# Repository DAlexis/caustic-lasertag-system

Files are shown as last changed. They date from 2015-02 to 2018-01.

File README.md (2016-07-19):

# Caustic Lasertag System
For Russian description scroll down the page.

Описание на русском --- внизу страницы.

## Overview
Caustic project is a full-featured outdoor and indoor wireless lasertag system. It consists of principial schemes, PCBs and firmware for devices used in lasertag game. For now, system consists of:
  - Player's gun
  - Player's sensor to detect shoots
  - Smart control point for 'capture the point' game and some other things
  - Bluetooth bridge that provide interconnection between your smartphone and all the devices in game near bridge
  - Android application (currently alpha state) to control the game and change settings

Caustic Lasertag System licensed under GPLv3. Third party code used in project may be licensed under other licences, see corresponding files and comments in the sources. Copyright 2016, see AUTHORS file.

## Project structure
Here is a directories description:
  - `Android/` --- Android application to control the game and change settings 
  - `cpp-sources/` --- MCU firmware. Here:
     - `bootloader-usb/` is a reference to https://github.com/DAlexis/stm32-usb-bootloader --- bootloader that supports cardreader functionality and flash controller from file `flash.bin`
     - `universal-device/` --- universal firmware for any Caustic LTS device.  
  - `Docs/` --- some datasheets and useful documents for project
  - `media/` --- sounds and its raws. Most of them were get from https://www.freesound.org/
  - `schematic/` --- electic schemes, PCBs and gerbers made with KiCad
  - `tools/` --- some scripts to simplify primitive jobs
  - `sdcards/` --- samples of devices' SD cards containment

## How to build firmware
Now only Linux OS supported to build Caustic LTS firmware, but I use `CMake` so add Windows support should not be a very complicated task.

You need to install `cmake`, `arm-none-eabi-gcc` compiler **with** `arm-none-eabi-newlib` and `arm-none-eabi-binutils` installed, and installation dirs should be in `$PATH`. Simply installation from your distro's repository usually enough. To flash the MCU with ST-link programmer you should install `stlink` utility. Then:

  - Clone this repository:
    
    `git clone https://github.com/DAlexis/caustic-lasertag-system.git`
  - Go to `cpp-sources` directory:
    
    `cd caustic-lasertag-system/cpp-sources`
  - Download git submodule containing bootloader:
    
    `git submodule init && git submodule update`
  - Run `build.sh` for debug build and `build.sh release` for release one

Then, to program the board:
  - Connect ST-link programmer to the board and to yout PC's USB
  - To flash main firmware run
  
    `flash-universal-device.sh`
  - To flash bootloader run
  
    `flash-bootloader.sh`
    To flash release version add `release` parameter to both scripts

    **NOTE:** flashing bootloader means removing previous firmware. To flash main program after flashing bootloader you should rename `universal-device.bin` to `flash.bin` and copy it to sd-card's root, then reboot device.

  - Then, copy proper sh-card containment to your device's sd-card. For example, for gun you should copy all files and dirs from `sdcards/rifle` to gun's sd-card.

# Лазертаг-система Caustic
Caustic --- это полноценная беспроводная система для внеаренного и аренного лазертага. Проект содержит принципиальные схемы, печатные платы, прошивки микроконтроллера и другой необходимый код. На данный момент, система включает:
  - Оружие игрока
  - Датчики попадания ("головная повязка") для игрока
  - Умная контрольная точка для игры в "захват точки", поддерживающая другие вспомогательные функции
  - Bluetooth-мост, позволяющий подключать смартфон одновременно к любому количеству устройств системы
  - Приложение для Android (на данный момент в альфа-версии) для управления игрой и настройки игровых устройств

Система Caustic лицензирована под GPLv3. Система включает код тертьих лиц, который может быть лицензирован под другими лицензиями. Copyright 2016, Алексей Булатов. 

## Структура проекта
Проект устроен следующим образом:
  - `Android/` --- Приложение для Android 
  - `cpp-sources/` --- Прошивка для контроллера
     - `bootloader-usb/` --- ссылка на https://github.com/DAlexis/stm32-usb-bootloader --- загрузчик, превращающий устройство в кардридер, если при запуске оно подключено к компьютеру по USB. Прошивает контроллер из файла `flash.bin`
     - `universal-device/` --- универсальная прошивка для любого устройства системы Caustic
  - `Docs/` --- даташиты, документация и некоторые полезные документы
  - `media/` --- звуки и их исходники. по большей части, взяты с https://www.freesound.org/
  - `schematic/` --- схемы, печатные платы, герберы, сделанные в KiCad
  - `tools/` --- некоторые скрипты, упрощающие некоторые простые действия
  - `sdcards/` --- содержимое SD-карт для устройств разных типов

## Как собрать прошивку и загрузчик
На данный момент поддерживается сборка только из-под Linux, однако проект использует `CMake`, так что добавить поддержку Windows не составит труда.

У вас дожен быть установлен `cmake`, компилятор `arm-none-eabi-gcc`, **включая** `arm-none-eabi-newlib` и `arm-none-eabi-binutils`. Компилятор должен быть доступен в `$PATH`. Обычно, достаточно просто установить соответствующие пакеты из репозитория вашего дистрибутива. Для прошивки нужен программатор ST-link и соответствующая утилита `stlink`. 

Загрузчик **не является** обязательным.

Итак, для установки:

  - Склонируйте этот репозиторий:
    
    `git clone https://github.com/DAlexis/caustic-lasertag-system.git`
  - Перейдите в папку `cpp-sources`:
    
    `cd caustic-lasertag-system/cpp-sources`
  - Инициализируйте и загрузите подмодуль, содержащий загрузчик:
    
    `git submodule init && git submodule update`
  - Запустите `build.sh` для сборки в режиме build, или `build.sh release` для сборки в release

Теперь, чтобы запрограммировать устройство:
  - Подключите программатор к плате устройства и к компьютеру. Включите питание устройства
  - Чтобы прошить основную программу, наберите
  
    `flash-universal-device.sh`
  - Чтобы прошить загрузчик:
  
    `flash-bootloader.sh`
    Чтобы прошить программу, собранную в release, добавьте параметр `release` к каждому из скриптов.

    **ВАЖНО:** При прошивке загрузчика стирается всё, что до этого было зашито в контроллер. Поэтому после прошивки загрузчика нужно сделать следующее: переименовать `universal-device.bin` в `flash.bin` и положить в корень sd-карты (это можно сделать, просто подключив устройство по USB к компьютеру). После перезагрузки устройства загрузчик автоматически зальет прошивку в контроллер. Вообще говоря, можно вообще не использовать загрузчик.

  - Скопируйте необходимое содержимое на sd-карту. Например, если устройство --- это оружие игрока, скопируйте всё содержимое `sdcards/rifle` на карту устройства. Именно так прошивка поймёт, "кем быть".

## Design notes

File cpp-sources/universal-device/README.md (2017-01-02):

# Caustic universal device source code home

Directories meaning:
 - `low-level` contains C code that adopted from generated by STM32CubeMX. This code
 should not be heavily modified. When newer versuons of stm32 HAL libraries
 appear this part may be regenerated by CubeMX
 - `high-level` contains main C++ code of the project

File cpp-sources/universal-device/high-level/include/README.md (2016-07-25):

# Directories structure
For Russian description translate this text and make pull-request, no problem :)

We are in `cpp-sources/universal-device` directory. Here is directories structure desription:
This is "shared" directories used by any kind of lasertag device:
- `system-config/` -- C headers used to configure middleware and standard libraries. Contains system libs dependencies, not used anywhere except system part.
- `hal/` -- declaration of interfaces to manipulate MCU hardware (IO pins, SPI, sound, ...). This interfaces are thrivial and simply wrap standard libraries.
- `hw/` -- realization of interfaces from `hal/`. Files from this directory should not be included anywhere, all access to objects provided over interfaces in `hal` and some `extern` variables/
- `dev/` -- "devices", ready-to-use blocks that are providing more complicated functionality than interfaces from `hal/`. For example, classes like `WavPlayer`, `Random`, `RC552Wrapper`, `RGBLeds`. Some of them may contains third-party code or be a wrappers of it. Third-party code shoud be moved to `Middlewares/Third_Party/`
- `core/` -- OS wrappers, system initialization code (except HW-specific), some utils (TODO: move it to `utils/`?)
- `network/` -- network layer for radio transmission
- `rcsp/` -- Remote Control And Synchronization Protocol -- all things related to this this protocol usage
- `ir/` -- all about infrared receiver. TODO: Class `MilesTag2Transmitter` should be replaces by `IRPresentationTransmitterMT2`
- `utils/` -- some utils. Marcos, workarounds to fix some problems and other.
- `communication/` -- now contains one .hpp file with head sensor -- rifle communication helping classes
- `device/` -- base classes used by any kind of complete device
- `game/` -- generic game control, statistics and other. Now not ready, work in process

This directories related to concrete types of devices
- `bluetooth-bridge/` -- logic for bluetooth bridge
- `rifle/` -- logic for lasertag gun
- `head-sensor/` -- logic for player's head sensor
- `smart-point/` -- logic for smart point

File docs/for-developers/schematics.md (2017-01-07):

---
layout: documentation
title: Принципиальные схемы
show-on-header: false
is-documentation: true
---

## Принципиальные схемы

Актуальные версии схем и плат достуны в репозитории [по ссылке](https://github.com/DAlexis/caustic-lasertag-system/tree/master/schematic) .

Для тех, кому не хочется возиться с KiCad, вот последние схемы в виде .pdf-документа:
[повязка]({{ site.url }}/images/hs-mono-g431.pdf) под корпус G431 и 
[оружие]({{ site.url }}/images/rifle-mono-v1.pdf), компактная одноплатная версия.

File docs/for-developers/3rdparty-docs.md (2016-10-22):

---
layout: documentation
title: Сторонняя документация
show-on-header: false
is-documentation: true
---

## Сторонняя документация

Здесь собрана документация, полезная при разработке лазертага.

### Miles Tag 2

Протокол инфракрасного канала, де-факто ставший стандартом для 
лазертаг-разработчиков, как для коммерческих производителей, так и для 
любителей:
[MT2-Protocol.pdf]({{ site.url }}/documents/MT2-Protocol.pdf)

### Datasheets 

Даташиты для наиболее важных компонент:

 - [NRF25L01]({{ site.url }}/documents/datasheets/nRF24L01_Product_Specification_v2_0.pdf)
 --- радиомодули, используемые системой

 - [HC-05]({{ site.url }}/documents/datasheets/HC-05_bluetooth_module.pdf)
 --- Bluetooth-модуль для связи с Android-устройствами

 - [MFRC522 card reader]({{ site.url }}/documents/datasheets/MFRC522.pdf)
 --- считыватель RFID-карт и [MIFARE Classic 1K]({{ site.url }}/documents/datasheets/MF1S503x-89574.pdf)
 --- документация на распространенный тип карточек, поддерживаемый системой
 
 - [TSOP4856]({{ site.url }}/documents/datasheets/TSOP4856.pdf)
 --- стандартный демодулирующий ИК-приемник для датчиков поражения
 
 - [RM0008 Reference Manual](http://www.st.com/content/ccc/resource/technical/document/reference_manual/59/b9/ba/7f/11/af/43/d5/CD00171190.pdf/files/CD00171190.pdf/jcr:content/translations/en.CD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)
 --- документация на микроконтроллер STM32F103RET6. В странной системе наименования
 документов STMicroelectronics так называется полное описание
 микроконтроллеров STM32F101xx, STM32F102xx, STM32F103xx, STM32F105xx и STM32F107xx 
 
 - Более мелкие детали:
 
   * [MCP73831]({{ site.url }}/documents/datasheets/MCP73831.pdf) --- контроллер 
   зарядки Li-ion-аккумуляторов
   
   * [NCP551]({{ site.url }}/documents/datasheets/NCP551.pdf) --- low-dropout
   стабилизатор напряжения питания
   
   * [PAM8403]({{ site.url }}/documents/datasheets/PAM8403.pdf) --- двухканальный
   усилитель звука класса D мощностью 3 Вт
   
   * [TSAL6100]({{ site.url }}/documents/datasheets/tsal6100.pdf) --- мощный
   ИК-светодиод
   
   * [IRLML2502]({{ site.url }}/documents/datasheets/irlml2502trpbf.pdf) --- 
   <<логический>> n-канальный полевой транзистор, открывается лог. <<1>>
   с микроконтроллера
   
   * [USBLC6-4SC6]({{ site.url }}/documents/datasheets/USBLC6-4SC6.pdf) --- 
   электростатическая защита USB-порта на быстродействующих диодах

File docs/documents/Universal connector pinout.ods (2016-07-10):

 |  |  | RFID |  | Nokia 5110
N | Label | MCU | N | label | N | label
10 | I2C_SDA / UART_RX / GPIO | PB11 |  |  | 2 | CE
9 | I2C_SCL / UART_TX / GPIO | PB10 |  |  | 1 | RST
8 | GPIO | PB9 |  |  | 3 | D/C
7 | 3.3 V |  | 8 | VCC | 6 | VCC
6 | GND |  | 6 | GND | 8 | GND
5 | GPIO | PB6 | 7 | RST
4 | MISO (SPI3) | PB4 | 4 | MISO
3 | MOSI (SPI3) | PB5 | 3 | MOSI | 4 | DIN (MOSI)
2 | SCK (SPI3) | PB3 | 2 | SCK | 5 | CLK (SCK)
1 | GPIO | PA15 | 1 | SDA (slave select)

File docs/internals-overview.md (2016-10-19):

---
layout: default
title: Устройство
header-nav: true
---

About
========
Caustic -- игровая система для внеаренного и аренного лазертага
с открытым исходным кодом и 
* Lorem Ipsum
* dolor sit amet

About this site
===============
* This is static and use [Jekyll](https://github.com/jekyll/jekyll)

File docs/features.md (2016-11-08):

---
layout: default
title: Обзор системы
show-on-header: true
---

Caustic -- игровая система внеаренного и аренного лазертага
с открытым исходным кодом. Caustic -- <<тяжелая>> система, нацеленная на
максимальные возможности ценой сложности прошивки и оборудования.

## Что умеет Caustic?
 В Caustic реализованы все базовые возможности, которые должны быть у каждой лазертаг-системы.
 - Игроки могут стрелять и убивать других игроков, могут возрoждаться на респауне и 
 захватывать контрольные точки
 - Беспроводное соединение между головной повязкой игрока и его оружием
 - Поддержка протокола Miles Tag 2, что обеспечивает совместимость с оборудованием
 большинства производителей
 - Поддержка нескольких экземпляров оружия на одного игрока
 - Поддержка нескольких зон поражения для <<головной повязки>>, позволяющая
 настроить различный урон для разных частей тела
 - Дисплей на оружии, показывающий состояние игрока

### Главные фишки системы:
 - Управление игрой и изменение настроек через Android-приложение. В отличие
 от имеющихся на рынке систем, есть возможность изменения настроек одновременно
 многих устройств
 - <<Обратная связь>> --- при ранении, убийстве игрока вражеской команды
 или при ранении игрока своей команды раздается звуковое оповещение, которое,
 в отличие от всех имеющихся на рынке систем, накладывается на звук стрельбы.
 Это позволяет отчетливо различать количество попаданий, не прекращая очередь.
 При этом оповещения о ранении, убийстве или friendly fire различаются
 - Горячая смена оружия при помощи индивидуальных RFID-карт. Нужно только
 поднести карту к оружию, и оно автоматически ассоциируется с хозяином карты

## Их чего состоит Caustic?
- <<Головная повязка>> игрока
- <<Оружие>> игрока, никаких проводов!
- <<Контрольная точка>> --- универсальное игровое устройство с кнопками,
экраном, динамиками и радиосвязью для реализации различных игровых сценариев
- Bluetooth-мост --- устройство, через которе ваш смартфон получает доступ
к любому устройству системы. Связывается со смартфоном по Bluetooth.

## На чем это работает?
- Ядром системы является микроконтроллер STM32F103RET6 в корпусе LQFP-64. 
- Для хранения звуков, настроек и т.п. в каждом устройстве установлена
micro-SD--карта
- Для беспроводной связи применяются радиомодули nrf24l01 --- распространенные
в среде DIY устройства от Nordic Semiconductor.

## Как это запрограммировано?
Исходный код прошивки устройств системы написан на C++ с применением ООП, 
что позволяет легко модфицировать код --- например, добавлять поддержку 
новых протоколов или радиомодулей. Системой используется ОС реального 
времени FreeRTOS, благодаря чему минимизируются задержки при одновременной
обработке большого количества информации.

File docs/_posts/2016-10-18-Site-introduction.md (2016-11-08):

---
title: Запущена тестовая версия сайта проекта
layout: post
---

Видимо, пора. Поэтому запускается данный сайт :)
Здесь я буду выкладывать инструкции, техническую документацию, новости 
проекта и другую информацию. Надеюсь, сайт поможет:

- Пользователям системы собрать, прошить и настроить устройства
- Разработчикам, планирующим сделать вклад в развитие проекта
- Разработчикам, планирующим разрабатывать совместимые девайсы, или же просто интересующимся устройством Caustic.

Приветствуется всякое содействие проекту: баг-репорты (можно
просто пиcать мне на [AlexeyABulatov@yandex.ru](mailto:AlexeyABulatov@yandex.ru),
разработка плат, написание кода, документации, дизайн этого сайта и т.п.

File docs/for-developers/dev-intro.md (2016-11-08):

---
layout: documentation
title: Документация
show-on-header: true
is-documentation: false
---

## Документация

По мере обновления сайта здесь будет пополняться информация о <<внутренностях>>
системы. 

## Исходный код

Исходный код проекта Caustic, ключая прошивки, схемы, платы и 
Android-приложение представлен в этом [git-репозитории](https://github.com/DAlexis/caustic-lasertag-system).

## Документация Doxygen

[Читать документацию]({{ site.url }}/doxygen/html)

Doxygen --- система документирования исходного кода. Документация в виде
веб-страниц генерируется автоматически и содержит много инструментов для
облегчения понимания структуры кода: диаграммы зависимости классов, 
заголовочных файлов, вызовов функций. Обилие гиперссылок позволяет легко
переходить от одних участков кода к другим.
Например, чтобы наглядно увидеть, как устроен класс головной повязки игрока
`HeadSensor`, нужно посмотреть на [эту страницу]({{ site.url }}/doxygen/html/classHeadSensor.html)

Для уменьшения объёма, из документации исключены сторонние библиотеки и
код операционной системы (STM32 HAL, stdperiph, FreeRTOS, FatFS, USB-stack, ...),
поскольку они используются целиком без модификаций, и их документация 
доступна на официальных сайтах.

Обновление документации происходит не с каждым коммитом, поэтому в ней могут
быть незначительные отличия от текущего состояния проекта. Последняя версия
сгенерирована 18.03.2016.

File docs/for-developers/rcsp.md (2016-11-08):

---
layout: documentation
title: Протокол RCSP
show-on-header: false
is-documentation: true
---

## Протокол RCSP
RCSP (Remote Control and Synchronization Protocol) --- бинарный протокол
управления и синхронизации переменных устройств системы Caustic. Он
представляет собой универсальный API, позволяющий реализовать практически
любой мыслимый функционал.

### Использование в системе
RCSP является протоколом уровня представления и используется в системе
для передачи команд по разным каналам:

 - Через радиосвязь -- удаленное управление игрой, настройка оборудования,
 получение статистики, связь повязка-оружие и т.п.
 
 - Через ИК-канал -- команды ИК-протокола транслируются в команды RCSP и
 обратно. Однако RCSP-сообщение может быть передано непосредственно по
 ИК-каналу в случае, если используемый ИК-протокол не поддерживает нужного
 функционала
 
 - Запись и чтение из файлов на SD-карте. Настройки и состояние системы 
 сохраняется в виде RCSP-сообщений в файлах
 
 - Через RFID метки. Любая команда может быть записана на RFID-карте и
 использоваться в игре

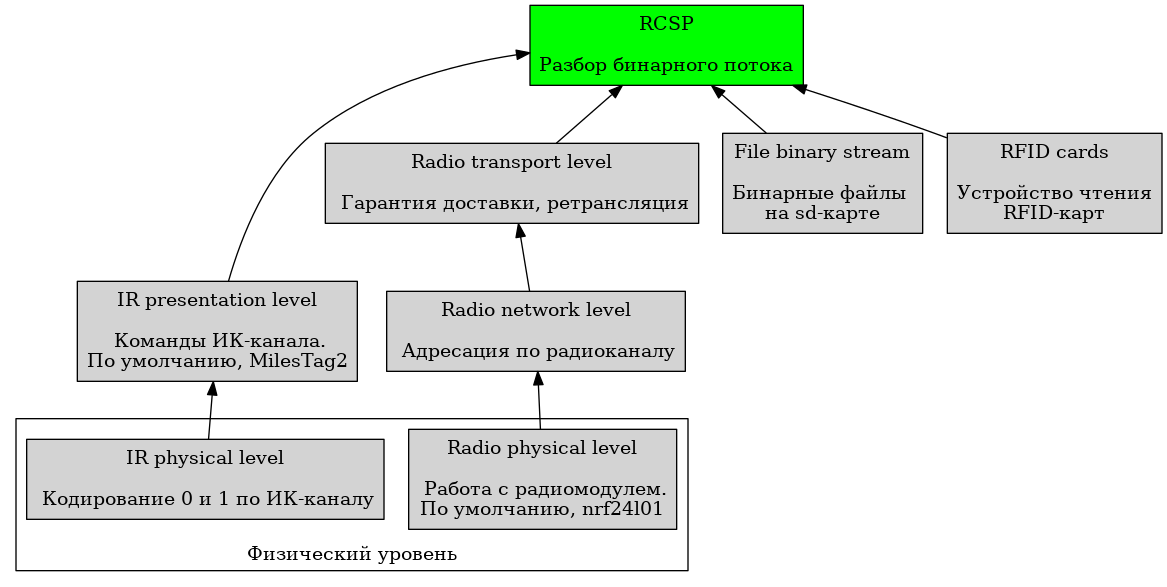
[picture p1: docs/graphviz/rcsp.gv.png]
Логика системы

 
### RCSP-сообщения
Единицей обмена данными через RCSP является сообщение. Сообщения могут
быть объединены в единый бинарный поток. Такой поток не требует дополнительной
метаинформации. Сообщение имеет следующую структуру, последовательно:

| 1 byte | 2 bytes | arg_size bytes |
|:-:|:-:|:-:|
| uint8_t arg_size | uint16_t op_code |  argument |

 - `arg_size` --- размер аргумента операции, принимает значения [0..255]
 - `op_code` --- код операции
 - `argument` --- аргумент операции. Отсутствует, если `arg_size == 0`

Таким образом, `arg_size` и `op_code` составляют заголовок сообщения. 
Поскольку размер сообщения всегда составляет `arg_size + 3` байт, сообщения
с неизвестным кодом операции могут быть пропущены без ущерба для остальных
сообщений, входящих в поток.

Тип операции задается двумя старшими битами `op_code`. Поддерживается 
3 типа операций:

| Тип |  Битовая маска  | Операция |
|:---:|:---:|:---|
|Set parameter (SP) | 01xxxxxxxxxxxxxx| Установить значение некоторой переменной в `argument` |
|Request parameter (RP) | 10xxxxxxxxxxxxxx| Запросить значение переменной |
|Call request (CR) | 00xxxxxxxxxxxxxx| Вызвать функцию с параметром `argument` |

Запросы Request parameter (RP) применяются только в ситуации, когда канал
связи, использующий протокол RCSP, двухсторонний. На данный момент это
справедливо только для радиоканала. RP-запрос подразумевает формирование
ответного сообщения, состоящего, в свою очередь, исключительно из 
SP-сообщений. Например:

 - Головная повязка имеет зарегистрированный в RCSP-системе 
 параметр healthCurrent. Оружие имеет такой же параметр для того, чтобы
 отображать его на дисплее. Но для этого требуется синхронизация.
 
 - Оружие посылает RP-запрос на головную повязку, для парамера healthCurrent.
 В ответ повязка формирует SP-сообщение со значением healthCurrent.
 
 - Когда оружие принимает SP-сообщение для параметра healthCurrent, значение
 одноименной переменной изменяется автоматически. Таким образом код, который
 отвечает за вывод текста на экран, выведет при следующем обновлении уже
 измененное значение.

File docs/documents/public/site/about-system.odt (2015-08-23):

# О системе Caustic

Caustic — это электронная начинка системы для игры в лазертаг, подходящая как для внеаренного, так и для аренного вариантов лазертага. Проект основан в сентябре 2014 г. На данный момент базовые функции системы находятся на стадии тестирования. Расширенные функции — на стадии разработки.

## Что уже умеет Caustic?

Последняя стабильная версия плат и прошивки поддерживает следующее:

Связь между оружием и повязкой осуществляется по радио, без проводов

Открытый ИК-протокол MilesTag2 (ссылка)

Для озвучки событий (выстрелы, респаун, ранение, и т. д.) используются звуковые файлы, записанные на microSD-карте. На каждое действие возможно произвольное количество вариантов озвучки (например, выстрелы больше не звучат однотипно)

Настройка оружия и повязки осуществляется через ini-файлы на карте памяти

К одной повязке может быть подключено любое количество таггеров, таким образом один игрок может иметь несколько единиц оружия

На повязке установлены RGB-светодиоды, каждая команда имеет свой цвет индикации попаданий

## Что внутри?

### Железо

Платы уже претерпели 2 ревизии. Последняя версия плат представляет собой «бутерброды» с размерами около 26x50 мм при толщине «бутерброда» не более 10мм как для оружия, так и для головной повязки.

«Бутерброд» состоит из двух плат:

- Универсальная плата-ядро с контроллером stm32f103ret6 и гнездом для microSD-карты
- Шилд, специфичный для каждого устройства и его комплектации. В том числе, планируется разработка упрощенных шилдов, доступных для домашнего изготовления «лазерно-утюжной» технологией.

Для звука применен усилитель PAM8603 — класс D, минимальная обвязка, крайне низкая розничная стоимость.

Радиомодуль — NRF24L01. Существует два варианта модуля: более мощной (радиус ~1км) и менее мощной (~50м). Пара слабых радиомодулей стоит дешевле, чем соединительные провода с разъёмами, что позволяет однозначно отказаться от проводов даже в самой дешевой версии.

### Софт

Код для stm32f103ret6 написан на С++. В данный момент проводится портирование на FreeRTOS. Разработка ведется под gcc-arm.

Особенностью программной реализации Caustic является продвинутый протокол взаимодействия между устройствами по радиоканалу. Протокол позволяет дистанционно считывать или изменять произвольные характеристики любого устройства, а также вызывать любые функции.

## Что будет в ближайшем будущем?

Устройство-база, позволяющее управлять игрой и изменять характеристики через Bluetooth. Такое устройство представляет собой мост между bluetooth и сетью на основе nrf24l01

Android-приложение для управления игрой

Механизм горячей смены оружия прямо в бою с минимумом телодвижений

## Политика распространения

Схемы, а также платы всех устройств будут в открытом доступе

Бинарная прошивка для всех устройств будет в открытом доступе

Открытие исходного кода не планируется в ближайшее время

Предполагается коммерческий выпуск готовых плат, наборов для самостоятельного монтажа или готовых к игре лазертаг-комплектов. Время покажет.

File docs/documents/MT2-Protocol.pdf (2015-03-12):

## The MilesTag 2 protocol

Christopher Malton

April 2011

This document aims to provide a complete reference to the MilesTag 2 protocol, as the documentation on the LaserTagParts website is sketchy at best. It covers all of the protocol in common use and supported in the stock MilesTag rmware as of 26th April 2011.

1

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

Figure 1: An example waveform for the MilesTag 2 protocol

## 1 The infrared protocol

The MilesTag 2 protocol is modulated onto a pulse-width-modulated (PWM) waveform. This PWM waveform either runs at 38, 40 of 56 kHz.
| The MilesTag 2 protocol is a series of pulses of this carrier wave beginning
with a 2400 microsecond (µS) long pulse. This is followed by a series of pulses either 1200µS or 600µS in length, representing 1 and 0 respectively. Each of the pulses is separated with a gap of 600µS of no carrier wave. The above is best explained by gure 1.

3

## 2 The data protocol

The data protocol is layered on top of the simple infrared protocol described in section 1. I will use the term packet to describe a collection of data bytes grouped together and sent following a single header. I use the term bytes loosely here, as in certain types of message, only six of eight bits are sent. There are two standard types of data packet: shot and message.

2.1 The shot packet

The shot packet is 14 bits in length, consisting of one bit for packet type, 7 bits for player ID, and 6 bits for team ID and damage.
This can be better represented as follows:
| [Header] - [0ppppppp] - [ttdddd]

The 0 signies a shot packet, ppppppp is replaced with the 7-bit player ID, tt is replaced with the team ID, and dddd is replaced with the damage value from the lookup table (see Appendix A).

2.2 The message packet

The message packet is a considerably more complex beast. It consists of one bit for packet type, 7 bits for the message ID, 8 bits for the message data, followed by 8 bits of message terminator.
This can be represented as follows:
| [Header] - [1mmmmmmm] - [dddddddd] - [0xE8]

The 1 signifying a message, followed by the message ID, its data, and then the message termination literal. It is generally accepted that the message ID includes the leading 1, so all message IDs referred to in this document will either be referred to by name, or in hexadecimal form including the leading bit. Message IDs will therefore all be equal to or higher than 0x80.
At the time of writing, there are 13 registered messages in the protocol table, and the data bytes are message specic. Each of the messages are described in the following sections.

2.2.1 0x80 - Add Health

The message ID 0x80 corresponds to Add Health, and its data byte is a value between 1 and 100, which will be added to the target player's health.

2.2.2 0x81 - Add Rounds

Add rounds adds the number of rounds specied in the data byte (between 1 and 100) to the tagger's current ammo count.

4

2.2.3 0x82 - Reserved

This message ID is reserved for future expansion.

2.2.4 0x83 - Command

There are numerous single-byte commands that can be sent, the following table
lists the data byte followed by the details of what that command does:
Data byte | Command name | Actions taken
0x00 | Admin Kill | Removes the remainder of a player's health
0x01 | Pause/Unpause | Pauses/unpauses the timer and all in-play actions
0x02 | Start Game | Starts a new game with the start delay active
0x03 | Restore defaults | Resets a tagger to its default (factory) settings.
0x04 | Respawn | Respawn a dead player
0x05 | Immediate new game | Start a new game, ignoring the start delay
0x06 | Full ammo | Restore a player's ammo counter to its initial value
0x07 | End game | Immediately end the current game
0x08 | Reset clock | Reset a player's clock to 00:00
0x09 | Reserved | Reserved for future expansion
0x0a | Initialize player | Resets the tagger
0x0b | Explode player | Causes the explosion sound eect to be played. Sets health to 0
0x0c | New game (ready) | Prepares taggers for the 0x02 start game command.
0x0d | Full health | Reset the player's heath to its initial value
0x0e | Reserved | Reserved for future expansion
0x0f | Full armour | Reset the player's armour to its initial value
0x10 | Reserved | Reserved for future expansion
0x11 | Reserved | Reserved for future expansion
0x12 | Reserved | Reserved for future expansion
0x13 | Reserved | Reserved for future expansion
0x14 | Clear scores | Resets all scoring data on the tagger
0x15 | Test sensors | Flash the sensor LEDs
0x16 | Stun player | Prevent the player doing anything for a few moments
0x17 | Disarm player | Set the player's ammo counter to 0.
2.2.5 | 0x84, 0x85, 0x86 - Reserved

These message IDs are reserved for future expansion.

2.2.6 0x87 - System Data

There are multiple types of system data. The table below outlines the currently in-use data bytes. All of these packets will exceed the 3-byte length prescribed in section 2.2. The extra bytes for each system data type are explained in the relevant sections.

5

Data byte | Meaning | Extra info
0x00 | Reserved
0x01 | Cloning Data | See Section 2.3
0x02 | Reserved
0x03 | Score Data (pt 1) | See Section 2.4
0x04 | Score Data (pt 2) | See Section 2.4
0x05 | Score Data (pt 3) | See Section 2.4
2.2.7 | 0x88, 0x89 - Reserved

These message IDs are reserved for future expansion.

2.2.8 0x8A - Clips pickup

Picked up clips from the ammo box ID given the in data eld (0-15)

2.2.9 0x8B - Health pickup

Picked up heath from the medic box ID given the in data eld (0-15)

2.2.10 0x8C - Flag pickup

Picked up ag ID given the in data eld (0-15)

6

2.3 Cloning data

For cloning, much more data is required to be sent. A further 36 bytes is sent after the 0xE8 byte to mark the end of the message.
This table starts from byte 4, which is the rst byte sent after the 0xE8.
Byte number | Description of data
4 | Reserved
5 | Reserved
6 | Reserved
7 | Team ID - See section 2.3.1
8 | Reserved
9 | Clips added by picking up an ammo box
10 | Health added by picking up a medic box
11 | Reserved (0x03 for 5.41)
12 | Hit LED timeout in seconds
13 | Sound set - See section 2.3.2
14 | Overheat limit in rounds/min
15 | Reserved
16 | Reserved
17 | Damage per shot - See section 2.3.3
18 | Clip size - 0xFF is unlimited
19 | Number of clips - 0xCA is unlimited
20 | Fire selector - See 2.3.4
21 | Number of rounds for burst mode
22 | Cyclic RPM - See 2.3.5
23 | Reload delay in seconds
24 | IR power - See 2.3.6
25 | IR range - See 2.3.7
26 | Tagger on/o settings - See 2.3.8
27 | Respawn health - See 2.3.9
28 | Reserved
29 | Respawn delay in tens of seconds
30 | Armour value
31 | Game on/o settings 1/2 - See 2.3.10
32 | Game on/o settings 2/2 - See 2.3.11
33 | Hit delay - See 2.3.12
34 | Start delay in seconds
35 | Death delay in seconds
36 | Time limit in minutes
37 | Maximum respawns
38 | Reserved (0xFF in 5.41)
39 | Checksum - See 2.3.13

7

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

2.3.5 | Byte 22 - Cyclic RPM
Value | RPM
0x00 | 250
0x01 | 300
0x02 | 350
0x03 | 400
0x04 | 450
0x05 | 500
0x06 | 550
0x07 | 600
0x08 | 650
0x09 | 700
0x0a | 750
0x0b | 800
2.3.6 | Byte 24 - IR power
Value | IR power
0x00 | Indoor
0x01 | Outdoor
2.3.7 | Byte 25 - IR range
Value | Range
0x01 | Minimum
0x02 | 10%
0x04 | 20%
0x07 | 40%
0x0A | 60%
0x0E | 80%
0x12 | Maximum
2.3.8 | Byte 26 - Tagger settings

These values are ORed together to get the value of this eld.
Value | Meaning
0x01 | Muzzle ash on
0x02 | Overheat feature on
0x04
0x08
0x10
0x20
0x40
0x80

9

2.3.9 | Byte 27 - Respawn health
Value | Health | Value | Health | Value | Health | Value | Health
0x01 | 1 | 0x14 | 20 | 0x27 | 115 | 0x39 | 250
0x02 | 2 | 0x15 | 25 | 0x28 | 120 | 0x3a | 300
0x03 | 3 | 0x16 | 30 | 0x29 | 125 | 0x3b | 350
0x04 | 4 | 0x17 | 35 | 0x2a | 130 | 0x3c | 400
0x05 | 5 | 0x18 | 40 | 0x2b | 135 | 0x3d | 450
0x06 | 6 | 0x19 | 45 | 0x2c | 140 | 0x3e | 500
0x07 | 7 | 0x1a | 50 | 0x2d | 145 | 0x3f | 550
0x08 | 8 | 0x1b | 55 | 0x2e | 150 | 0x40 | 600
0x09 | 9 | 0x1c | 60 | 0x2f | 155 | 0x41 | 650
0x0a | 10 | 0x1d | 65 | 0x30 | 160 | 0x42 | 700
0x0b | 11 | 0x1e | 70 | 0x31 | 165 | 0x43 | 750
0x0c | 12 | 0x1f | 75 | 0x32 | 170 | 0x44 | 800
0x0d | 13 | 0x20 | 80 | 0x33 | 175 | 0x45 | 850
0x0e | 14 | 0x21 | 85 | 0x34 | 180 | 0x46 | 900
0x0f | 15 | 0x22 | 90 | 0x35 | 185 | 0x47 | 950
0x10 | 16 | 0x23 | 95 | 0x36 | 190 | 0x48 | 999
0x11 | 17 | 0x24 | 100 | 0x37 | 195
0x12 | 18 | 0x25 | 105 | 0x37 | 195
0x13 | 19 | 0x26 | 110 | 0x38 | 200
2.3.10 | Byte 31 - Game on/o settings (1/2)

These values are ORed together to get the value of this eld.
Value | Meaning
0x01
0x02 | Hit LED enabled
0x04 | Friendly re enabled
0x08 | Unlimited clips enabled
0x10 | Zombie mode enabled
0x20 | Medics enabled
0x40 | Game boxes reset on respawn
0x80 | Game boxes are not used up
2.3.11 | Byte 32 - Game on/o settings (2/2)

These values are ORed together to get the value of this eld.

10

Value | Meaning
0x01
0x02
0x04 | Capture-the-ag display enabled
0x08 | Respawn enabled
0x10 | Tagger nicknames enabled
0x20 | Old IR level eld
0x40 | Full ammo reset on respawn
0x80 | Enable game mode
2.3.12 | Byte 33 - Hit delay
Value | Delay (seconds) | Value | Delay (seconds)
0x00 | 0.00 | 0x0c | 9
0x01 | 0.25 | 0x0d | 10
0x02 | 0.5 | 0x0e | 11
0x03 | 0.75 | 0x0f | 12
0x04 | 1 | 0x10 | 13
0x05 | 2 | 0x11 | 14
0x06 | 3 | 0x12 | 15
0x07 | 4 | 0x13 | 16
0x08 | 5 | 0x14 | 17
0x09 | 6 | 0x15 | 18
0x0a | 7 | 0x16 | 19
0x0b | 8 | 0x17 | 20
2.3.13 | Byte 39 - Checksum

The checksum is the sum of bytes 4 through 38, modulo 0x100. Example:

Sum of 0xA9 + 0xAA + 0x00 + .... + 0x00 = 0x153 Checksum is therefore 0x53

2.4 Scoring data

The scoring data comes in three chunks, and they always come in the triplet part 1, part 2, part 3. The rst contains some basic data about the player's game. The second and third are the list of times the player was hit by other players, and other players on their team.
Be aware that MilesTag out of the box supports scoring for up to 105 players..... but that those players don't all have names in the list.

11

2.4.1 | Scoring data (part 1)
Byte number | Description of data
4 | Player ID
5 | Team ID (see 2.3.1)
6 | Rounds red (lower byte)
7 | Rounds red (upper byte)
8 | Total hits (lower byte)
9 | Total hits (upper byte)
10 | Game time (minutes)
11 | Game time (seconds)
12 | Respawns
13 | Tagged out counter
14 | Flag counter
15 | Checksum (See 2.3.13)
All of the above should be self explanatory, however for the avoidance of any doubt, byte 7 should be multiplied by 256, and added to byte 6 to get the total rounds red. The same applies to bytes 9 and 8 for total hits.
The checksum is computed as in 2.3.13, but using bytes 4 through 14.

2.4.2 Scoring data (part 2)

This scoring data provided in this packet shows all hits that were recieved by the player.
Byte number | Description of data
4 | Reserved
5 | Hits by 000 Eagle (lower)
6 | Hits by 000 Eagle (upper)
7 | Hits by 001 Joker (lower)
8 | Hits by 002 Joker (upper)
215 | Hits by 105 (lower)
216 | Hits by 105 (upper)
217 | Checksum (See 2.3.13)
Byte 6 must be multiplied by 256, and added to byte 5, and this will give the number of times that the player this data came from was shot by the player referenced by the byte ID.
The checksum is computed as in 2.3.13, but using bytes 4 through 216.

2.4.3 Scoring data (part 3)

This scoring data provided in this packet shows hits from the same colour team (traitor shots) that were recieved by the player.

12

Byte number | Description of data
4 | Reserved
5 | Hits by 000 Eagle (lower)
6 | Hits by 000 Eagle (upper)
7 | Hits by 001 Joker (lower)
8 | Hits by 002 Joker (upper)
215 | Hits by 105 (lower)
216 | Hits by 105 (upper)
217 | Checksum (See 2.3.13)
Byte 6 must be multiplied by 256, and added to byte 5, and this will give the number of times that the player this data came from was shot by the player referenced by the byte ID.
The checksum is computed as in 2.3.13, but using bytes 4 through 216.
A | Player ID reference
ID | Display name | ID | Display name | ID | Display name
0x00 | Eagle | 0x19 | Rambo | 0x32 | Micro
0x01 | Joker | 0x1a | Snake | 0x33 | LgtMG
0x02 | Raven | 0x1b | Audie | 0x34 | HvyMG
0x03 | Sarge | 0x1c | Sting | 0x35 | ZOOKA
0x04 | Angel | 0x1d | Zeena | 0x36 | ROCKT
0x05 | Cosmo | 0x1e | Bugsy | 0x37 | GRNDE
0x06 | Gecko | 0x1f | Viper | 0x38 | CLYMR
0x07 | Blaze | 0x20 | Jewel | 0x39 | MINE
0x08 | Camo | 0x21 | Genie | 0x3a | BOMB
0x09 | Fury | 0x22 | Logan | 0x3b | NUKE
0x0a | Flash | 0x23 | Razor
0x0b | Gizmo | 0x24 | Slick
0x0c | Homer | 0x25 | Venom
0x0d | Storm | 0x26 | Rocky
0x0e | Habit | 0x27 | Saber
0x0f | Click | 0x28 | Crush
0x10 | Ronin | 0x29 | Titan
0x11 | Lucky | 0x2a | Orbit
0x12 | Radar | 0x2b | Vixen
0x13 | Blade | 0x2c | Tank
0x14 | Ninja | 0x2d | Rogue
0x15 | Magic | 0x2e | Sheik
0x16 | Gonzo | 0x2f | Gizmo
0x17 | Cobra | 0x30 | Siren
0x18 | Pappy | 0x31 | Dozer

13
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

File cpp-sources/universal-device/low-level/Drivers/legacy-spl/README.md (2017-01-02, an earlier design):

# Legacy hardware library

This directory contains parts of legacy standard Perepherial Library (StdPeriph).
It is still used by FragmentPlayer and PwmIsrImpulseEmitter. Good job is to remove
this dependency away.

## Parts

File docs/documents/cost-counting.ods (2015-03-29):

Компонент | Цены |  |  |  |  | Head sensor rev1.1
 | Чип-НН | Промэлектроника 13 января 2015 | 1 Ом | Прочее | E-bay | Количество | Стоимость
stm32F103ret6 |  | 322 |  |  |  | 1 | 322
stm32f100cbt6b | 160 |  |  |  |  |  | 0
sd-card slot | 60 |  |  |  |  | 1 | 60
Стабилизатор 3.3В |  | 13 |  |  |  | 1 | 13
Стабилизатор 5В | 21 |  |  |  |  |  | 0
Транзистор IRLML2502 |  | 9,9 |  |  |  | 9 | 89,1
Кварц 8МГц |  | 7,4 |  |  |  | 1 | 7,4
Танталовый электролит 100мкФ 10В |  |  | 18 |  |  | 2 | 36
Клеммник, 3 винта |  |  | 10 |  |  | 10 | 100
Клеммник, 2 винта |  |  | 10 |  |  | 3 | 30
Лежащий разъём, 9 пин, пара M+FM |  | 13,9 |  |  |  | 1 | 13,9
Лежащий разъём, 3 пин, пара M+FM |  | 7,65 |  |  |  |  | 0
 |  |  |  | 0 |  |  | 0
Плата rifle rev1.1 |  |  |  | 55 |  |  | 0
Плата head-sensor rev 1.1 |  |  |  | 180 |  | 1 | 180
Радиомодуль NRF24L01 | 145 |  |  |  |  |  | 0
Радиомодуль NRF24L01 с усилителем |  |  |  |  | 259 | 1 | 259
ВСЕГО |  |  |  |  |  |  | 1110,4

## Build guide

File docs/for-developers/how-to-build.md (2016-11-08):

---
layout: documentation
title: Как собрать и прошить
show-on-header: false
is-documentation: true
---

## Как собрать прошивку и загрузчик
На данный момент поддерживается сборка только из-под Linux, однако проект использует `CMake`, так что добавить поддержку Windows не составит труда.

Чуть позднее в репозиторий будет добавлена готовая к использованию бинарная
прошивка.

В проекте Caustic присутствует две прошивки: сама лазертаг-система и загрузчик.
Закрузчик не является обязательным компонентом, однако он упрощает
перепрошивку оборудования у конечного пользователя. Загрузчик позволяет при подключении устройства 
по USB к компьютеру работать с картой памяти устройства, как с обычной флешкой.
Чтобы обновить прошивку системы при установленном загрузчике, достаточно
просто скопировать её в корень sd-карты. Загрузчик прошивается программатором
однократно.

Можно обойтись без загрузчика и прошивать систему на при помощи программатора.
Такой подход удобен при отладке, поскольку такая операция выполняется 
быстрее и не требует переподключать устройство к компьютеру.

Для обычных пользователя рекомендуется установить загрузчик.

### Установка необходимых пакетов

У вас дожен быть установлен `cmake`, компилятор `arm-none-eabi-gcc`, 
и необходимые компоненты: `arm-none-eabi-newlib` и `arm-none-eabi-binutils`.
Путь к компилятору должен быть указан в `$PATH`. Обычно, достаточно просто установить
соответствующие пакеты из репозитория вашего дистрибутива.

Для прошивки нужен программатор ST-link и соответствующая утилита `stlink`. 

### Ubuntu и производные

Вам понадобится `git` и `cmake`, если, конечно, их ещё нет в вашей системе:

`$ sudo apt install git cmake`

Для компиляции под STM32 нужно установить:

`$ sudo apt install gcc-arm-none-eabi gdb-arm-none-eabi binutils-arm-none-eabi libnewlib-arm-none-eabi libstdc++-arm-none-eabi-newlib`

Программу для работы с программатором ST-link придется установить из её репозитория:

`$ sudo apt install libusb-1.0-0-dev g++`

`$ git clone https://github.com/texane/stlink.git`

`$ cd stlink`

`$ make`

`$ cd build/Release`

`$ sudo make install`

`$ LD_LIBRARY_PATH=/usr/local/lib`

`$ sudo ldconfig`

Теперь вам доступна утилита `st-flash`, и всё должно собираться.

### Archlinux

Аналогично `git` и `cmake`:

`$ sudo pacman -S git cmake`

А также компилятор со всем необходимым:

`$ sudo pacman -S arm-none-eabi-binutils arm-none-eabi-gcc arm-none-eabi-gdb arm-none-eabi-newlib`

Программа для работы с ST-LINK есть в репозитории:

`$ sudo pacman -S stlink`

### Сборка

Теперь, чтобы собрать проект:

  - Склонируйте репозиторий проекта:
    
    `git clone https://github.com/DAlexis/caustic-lasertag-system.git`
    
  - Инициализируйте и загрузите подмодуль, содержащий загрузчик:
    
    `git submodule init && git submodule update`
    
  - Перейдите в папку `cpp-sources`:
    
    `cd caustic-lasertag-system/cpp-sources`
    
  - Запустите `build.sh` для сборки в режиме build, или `build.sh release` для сборки в release

Чтобы запрограммировать устройство с загрузчиком:

  - Подключите программатор к плате устройства и к компьютеру. Включите питание устройства.
  
  - Перейдите в папку `cpp-source` и запустите скрипт `./flash-bootloader.sh` или `./flash-bootloader.sh release` для прошивки релизной
    сборкой. После этого установится загрузчик.
  
  - Отключите питание устройства, отключите от него программатор. 
    Карта памяти должна быть отформатирована в FAT32 и установлена
    в устройство.
    Подсоедините устройство USB-кабелем к компьютеру, а затем включите. Если
    все прошло правильно, система опознает девайс, как флешку.
    
  - Из папки `cpp-sources/build/debug/universal-device` скопируйте на <<флешку>>
    файл `universal-device.bin` и переименуйте его в `flash.bin`.
    
  - Перезагрузите устройство и подождите 1 минуту. Этого достаточно, чтобы
    загрузчик записал прошивку.

Чтобы запрограммировать устройство без загрузчика:

  - Подключите программатор к плате устройства и к компьютеру. Включите питание устройства.
  
  - Перейдите в папку `cpp-source` и запустите скрипт `./flash-universal-device.sh` или `./flash-universal-device.sh release` для прошивки релизной сборкой.
    
Далее необходимо скопировать на устройство необходимые файлы. Например,
если устройство --- это оружие игрока, скопируйте всё содержимое `sdcards/rifle`
на карту устройства. Именно так прошивка поймёт, <<кем быть>>.
В случае головной повязки скопируйте всё из `sdcards/head-sensor`.
Не забудьте настроить адрес повязки и оружия в файле `config.ini`.

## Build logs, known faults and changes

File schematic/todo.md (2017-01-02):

Here will be things that should be one in next boards revisions

# Rifle monolith board

- No pull-up resistors on I2C bus

- Need 0.1uF capacitor just near PAM8403 (otherwise problems with loud sound)

- Micro USB: wire is too close to board's edge

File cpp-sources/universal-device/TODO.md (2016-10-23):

Caustic Universav Device to-do list
===================================

## Refactoring
* Remove singletones. Add service one ore more service locators

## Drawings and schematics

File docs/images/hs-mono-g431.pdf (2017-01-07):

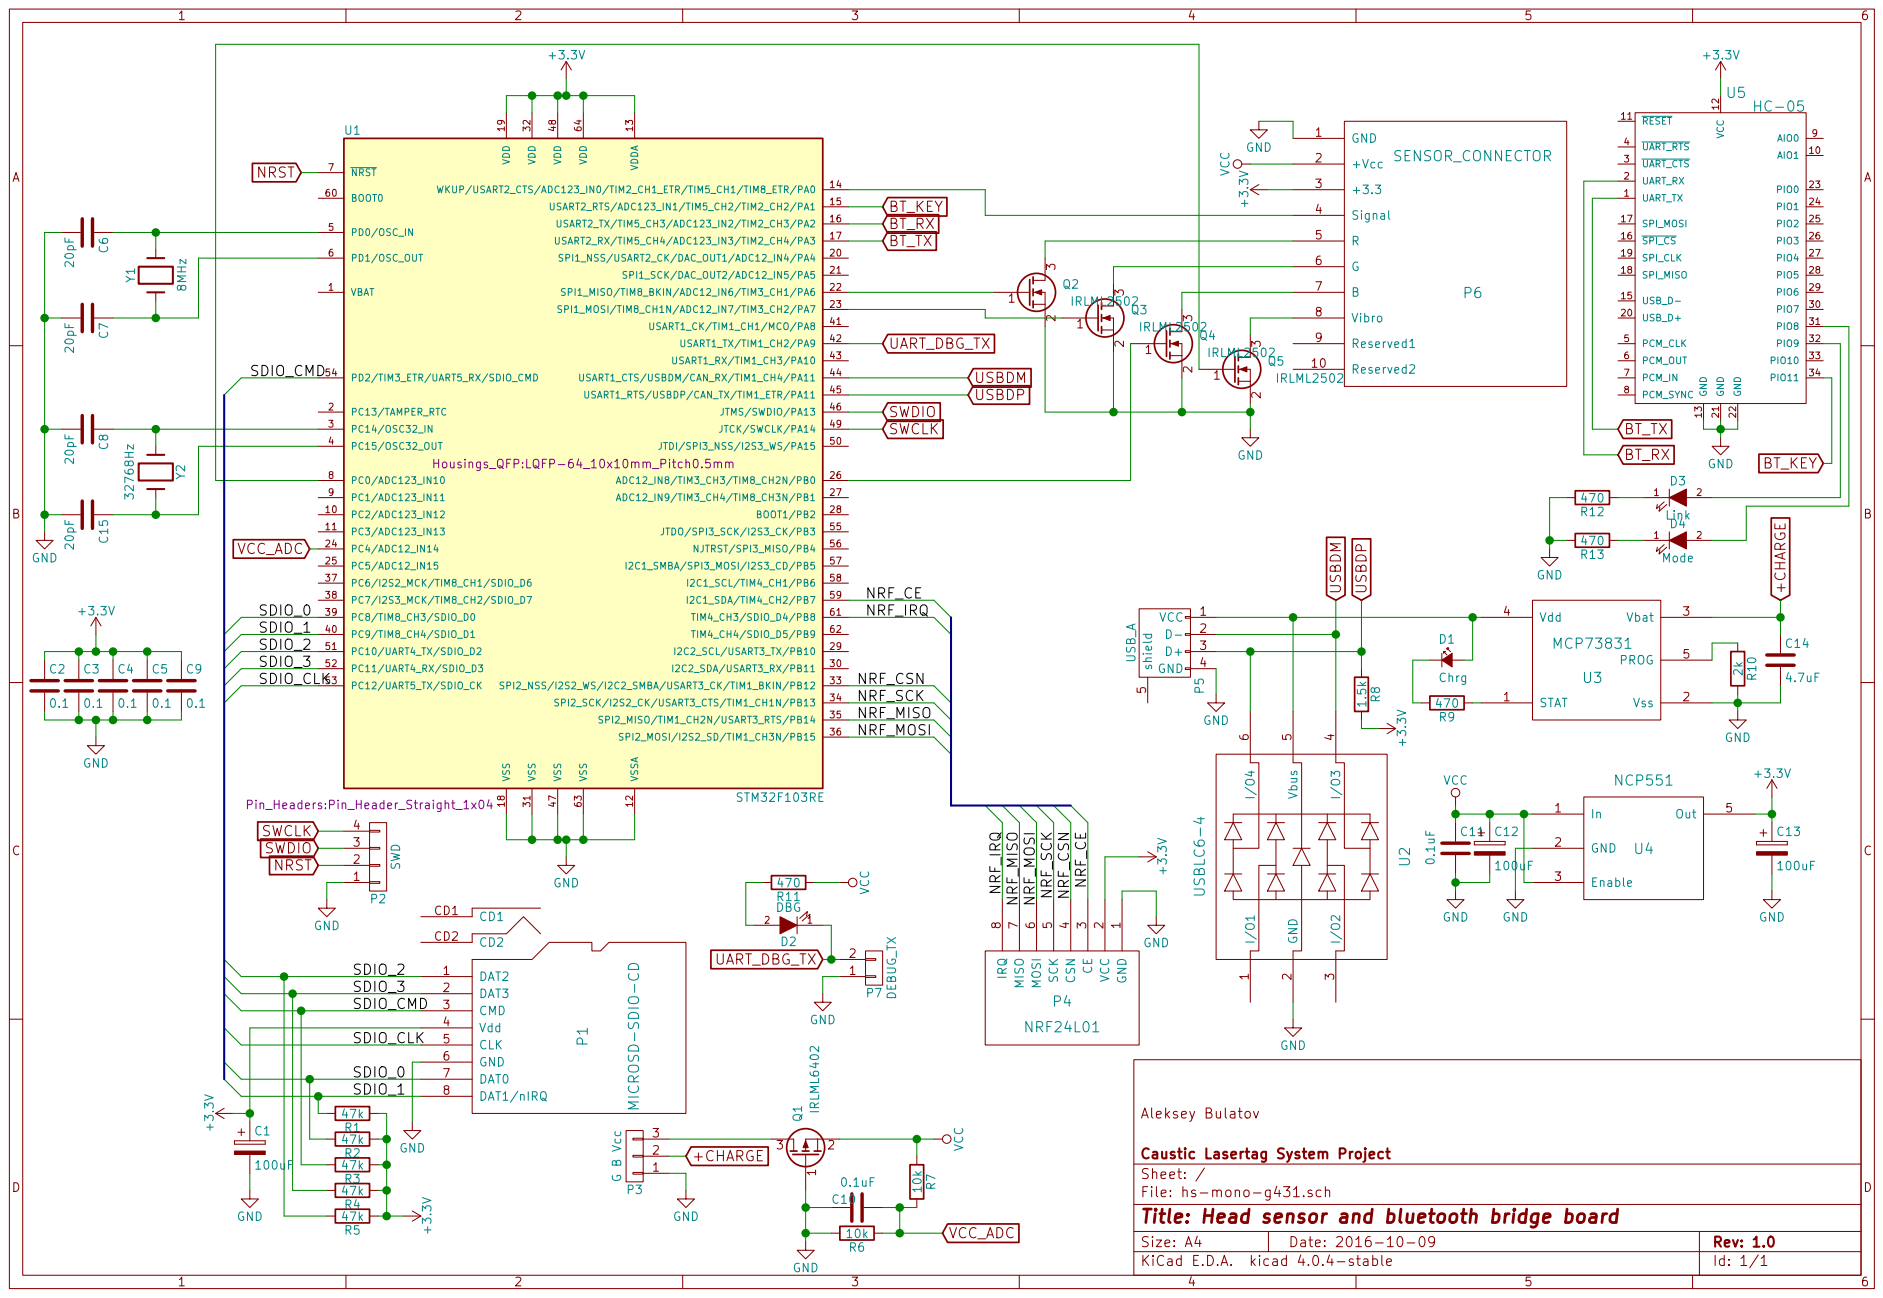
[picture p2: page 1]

NRF_MISO
NRF_MOSI

File: hs-mono-g431.sch Sheet: / Caustic Lasertag System Project

Id: 1/1 Title: Head sensor and bluetooth bridge board

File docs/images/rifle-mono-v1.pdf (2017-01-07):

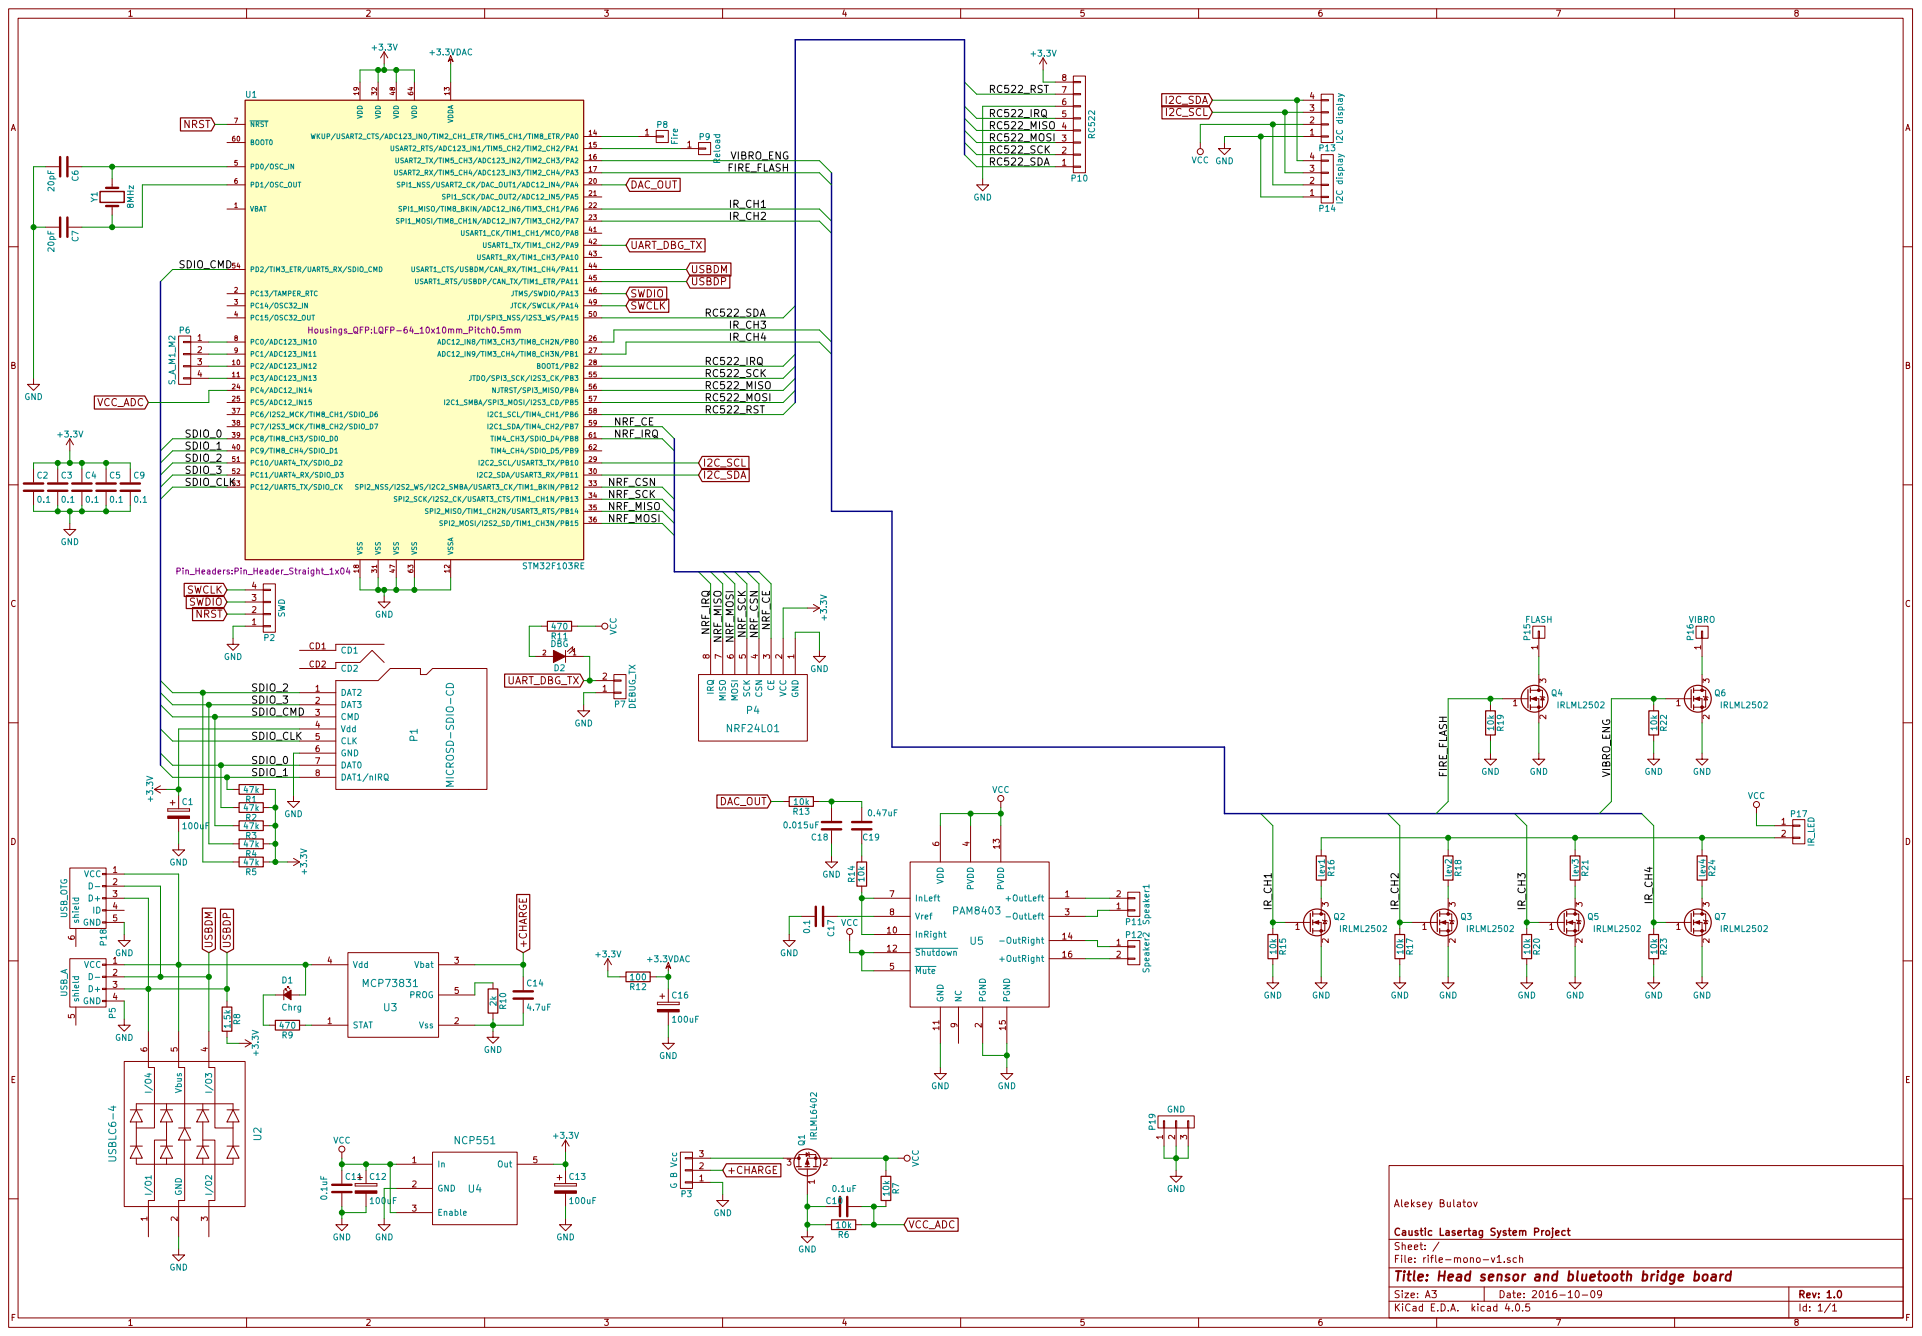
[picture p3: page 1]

4 P6 S_A_M1_M2 2 | RC522_IRQ

NRF_CSN
NRF_SCK
NRF_MISO
NRF_MOSI

File: rifle-mono-v1.sch Sheet: / Caustic Lasertag System Project

Id: 1/1 Title: Head sensor and bluetooth bridge board

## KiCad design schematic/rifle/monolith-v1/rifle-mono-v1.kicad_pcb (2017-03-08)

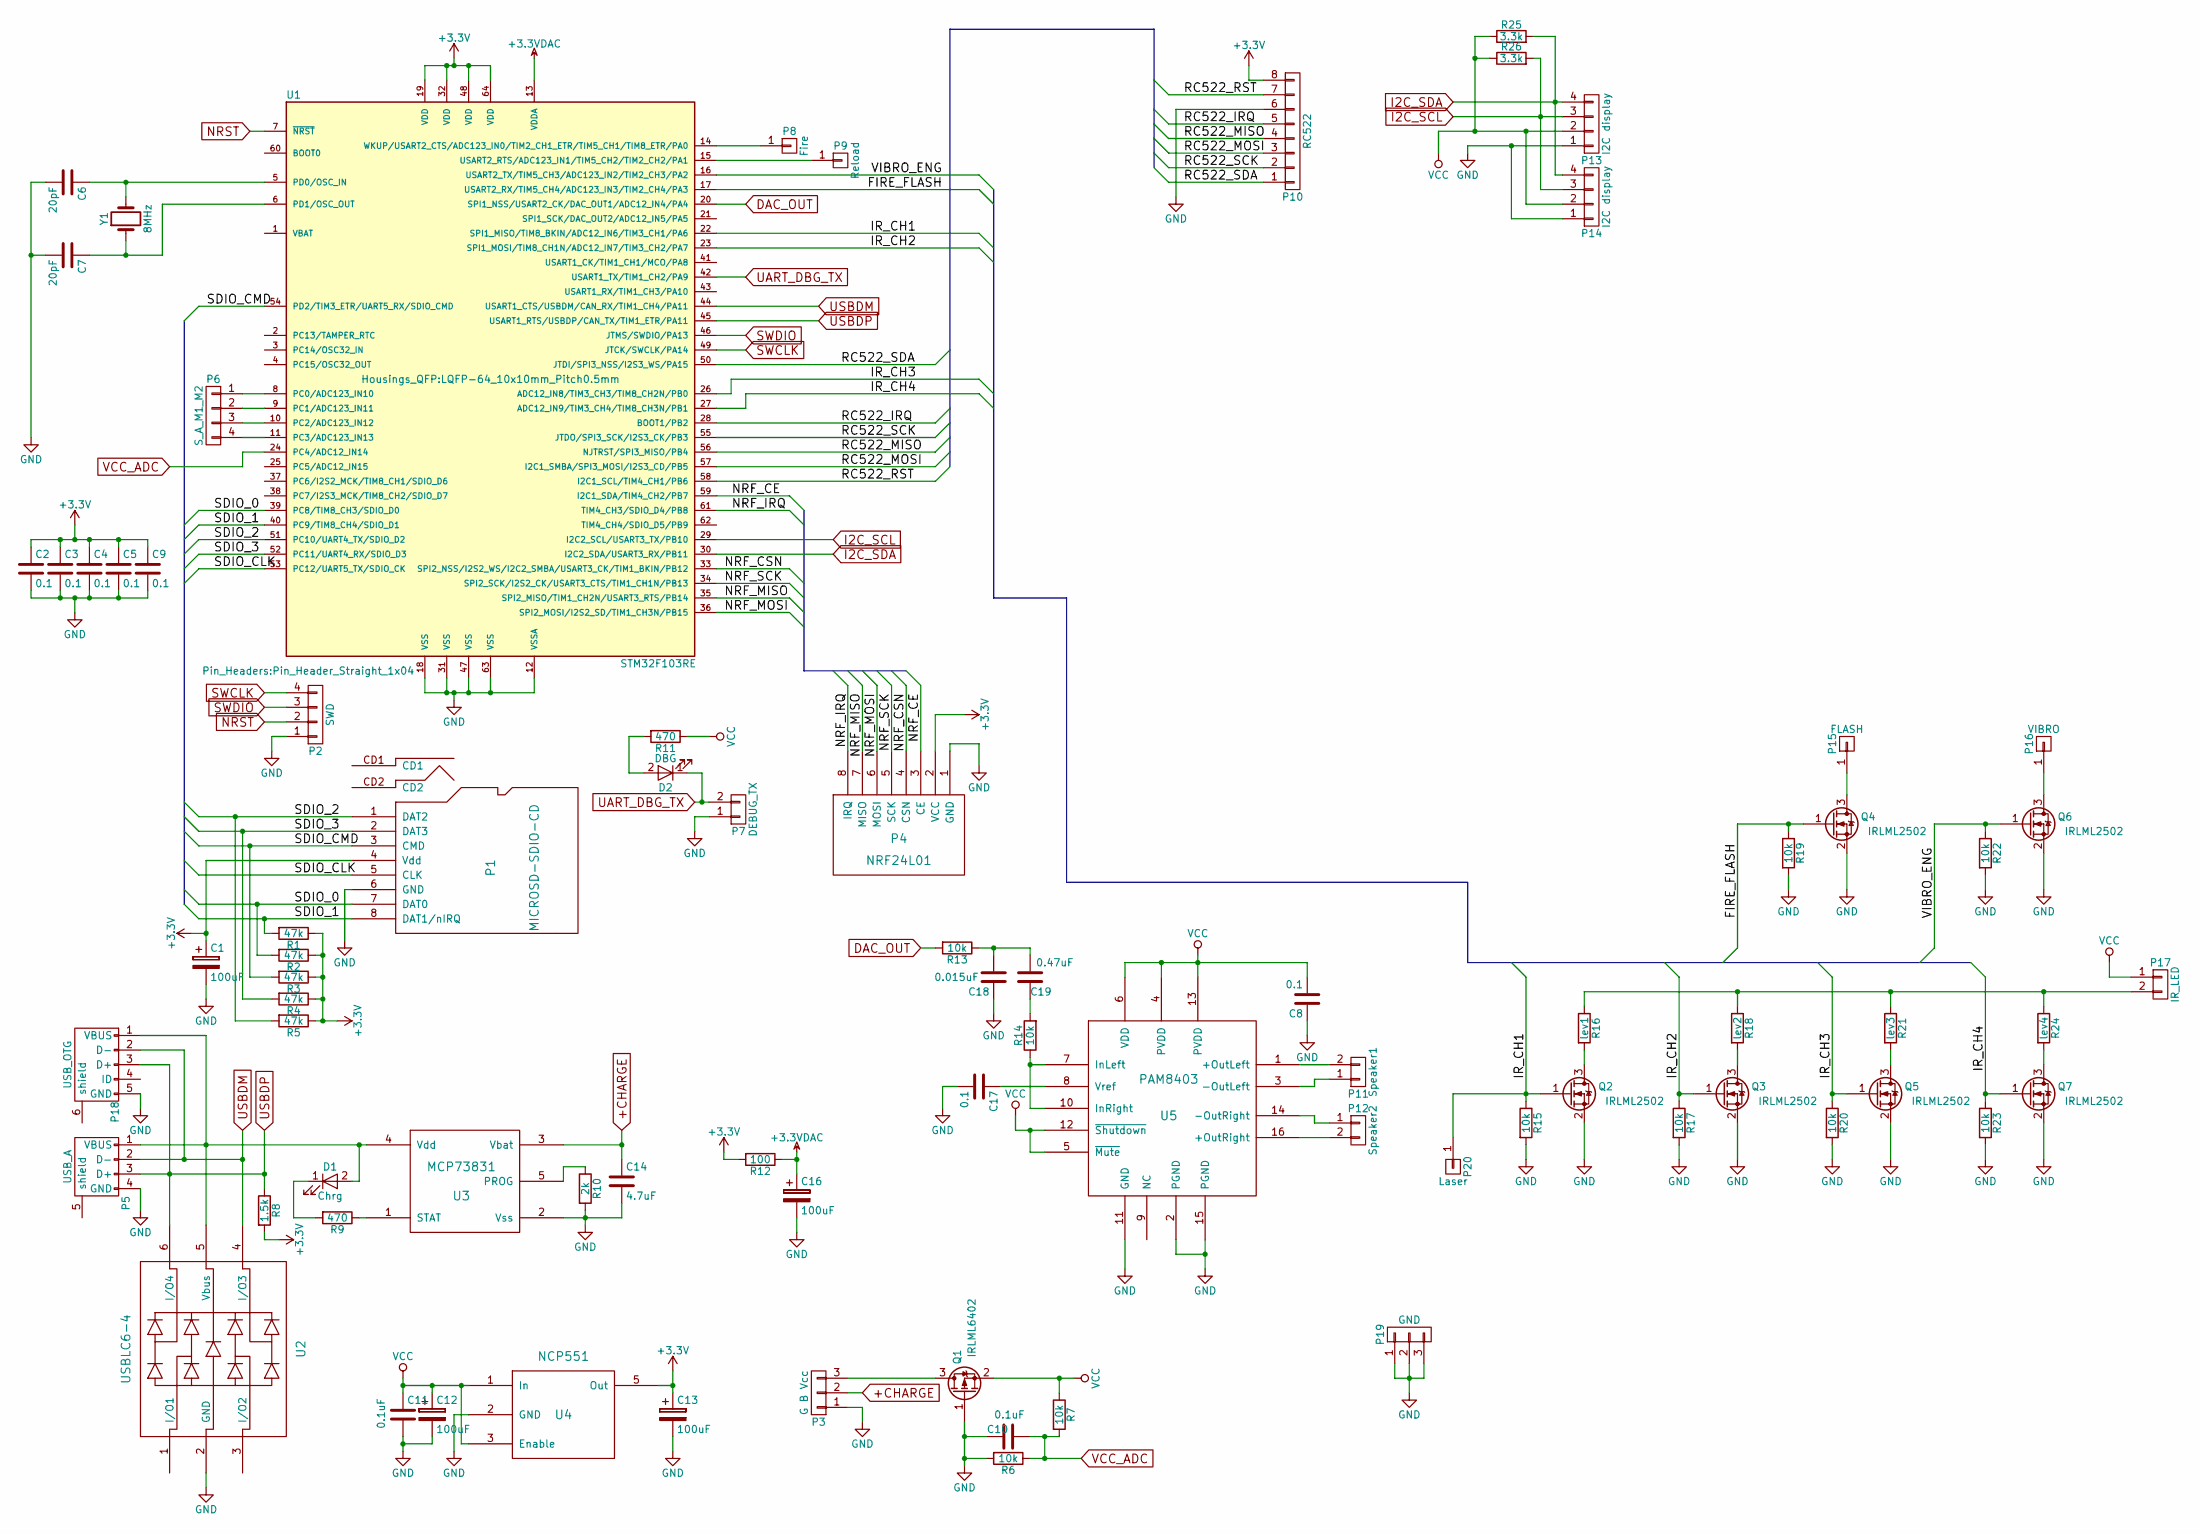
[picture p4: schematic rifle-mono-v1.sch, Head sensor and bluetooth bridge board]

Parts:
C1, C12, C13, C16: 100uF; TantalC_SizeB_EIA-3528_Reflow
C2, C3, C4, C5, C8, C9, C17: 0.1; C_0805
C6, C7: 20pF; C_0805
C10, C11: 0.1uF; C_0805
C14: 4.7uF; C_0805
C18: 0.015uF; C_0805
C19: 0.47uF; C_0805
D1: Chrg; LED_0805
D2: DBG; LED_0805
P1: MICROSD-SDIO-CD; MICROSD-CD-112J-WH
P2: SWD; Pin_Header_Straight_1x04
P3: G B Vcc; Pin_Header_Straight_1x03
P4: NRF24L01; NRF24L01-mini
P5: USB_A; USB_B
P6: S_A_M1_M2; Pin_Header_Straight_1x04
P7: DEBUG_TX; Pin_Header_Straight_1x02
P8: Fire; Pin_Header_Straight_1x01
P9: Reload; Pin_Header_Straight_1x01
P10: RC522; Socket_Strip_Straight_1x08
P11: Speaker1; Pin_Header_Straight_1x02
P12: Speaker2; Pin_Header_Straight_1x02
P13, P14: I2C display; Socket_Strip_Straight_1x04
P15: FLASH; Pin_Header_Straight_1x01
P16: VIBRO; Pin_Header_Straight_1x01
P17: IR_LED; Pin_Header_Straight_1x02
P18: USB_OTG; USB_Micro-B
P19: GND; Pin_Header_Straight_1x03
P20: Laser; Pin_Header_Straight_1x01_Pitch2.00mm
Q1: IRLML6402; SOT-23
Q2, Q3, Q4, Q5, Q6, Q7: IRLML2502; SOT-23
R1, R2, R3, R4, R5: 47k; R_0805
R6, R7, R13, R14, R15, R17, R19, R20, R22, R23: 10k; R_0805
R8: 1.5k; R_0805
R9, R11: 470; R_0805
R10: 2k; R_0805
R12: 100; R_0805
R16: lev1; R_0805
R18: lev2; R_0805
R21: lev3; R_0805
R24: lev4; R_0805
R25, R26: 3.3k; R_0805
U1: STM32F103RE; LQFP-64_10x10mm_Pitch0.5mm
U2: USBLC6-4; SOT-23-6
U3: MCP73831; SOT-23-5
U4: NCP551; SOT-23-5
U5: PAM8403; SO-16-N
Y1: 8MHz; Crystal_HC49-U_Vertical

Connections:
+3.3VDAC: C16.1, R12.1, U1.13 (VDDA)
+3V3: C1.1, C2.1, C3.1, C4.1, C5.1, C9.1, C13.1, P1.4 (Vdd), P4.2 (VCC), P10.8, R1.1, R2.1, R3.1, R4.1, R5.1, R8.2, R12.2, U1.19 (VDD), U1.32 (VDD), U1.48 (VDD), U1.64 (VDD), U4.5 (Out)
+CHARGE: C14.1, P3.2, U3.3 (Vbat)
/FIRE_FLASH: Q4.1 (G), R19.1, U1.17 (USART2_RX/TIM5_CH4/ADC123_IN3/TIM2_CH4/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)
/IR_CH1: P20.1, Q2.1 (G), R15.1, U1.22 (SPI1_MISO/TIM8_BKIN/ADC12_IN6/TIM3_CH1/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)
/IR_CH2: Q3.1 (G), R17.1, U1.23 (SPI1_MOSI/TIM8_CH1N/ADC12_IN7/TIM3_CH2/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)
/IR_CH3: Q5.1 (G), R20.1, U1.26 (ADC12_IN8/TIM3_CH3/TIM8_CH2N/PB0)
/IR_CH4: Q7.1 (G), R23.1, U1.27 (ADC12_IN9/TIM3_CH4/TIM8_CH3N/PB1)
/NRF_CE: P4.3 (CE), U1.59 (I2C1_SDA/TIM4_CH2/PB7)
/NRF_CSN: P4.4 (CSN), U1.33 (SPI2_NSS/I2S2_WS/I2C2_SMBA/USART3_CK/TI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)
/NRF_IRQ: P4.8 (IRQ), U1.61 (TIM4_CH3/SDIO_D4/PB8)
/NRF_MISO: P4.7 (MISO), U1.35 (SPI2_MISO/TIM1_CH2N/USART3_RTS/PB14)
/NRF_MOSI: P4.6 (MOSI), U1.36 (SPI2_MOSI/I2S2_SD/TIM1_CH3N/PB15)
/NRF_SCK: P4.5 (SCK), U1.34 (SPI2_SCK/I2S2_CK/USART3_CTS/TIM1_CH1N/P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)
/RC522_IRQ: P10.5, U1.28 (BOOT1/PB2)
/RC522_MISO: P10.4, U1.56 (NJTRST/SPI3_MISO/PB4)
/RC522_MOSI: P10.3, U1.57 (I2C1_SMBA/SPI3_MOSI/I2S3_CD/PB5)
/RC522_RST: P10.7, U1.58 (I2C1_SCL/TIM4_CH1/PB6)
/RC522_SCK: P10.2, U1.55 (JTDO/SPI3_SCK/I2S3_CK/PB3)
/RC522_SDA: P10.1, U1.50 (JTDI/SPI3_NSS/I2S3_WS/PA15)
/SDIO_0: P1.7 (DAT0), R2.2, U1.39 (PC8/TIM8_CH3/SDIO_D0)
/SDIO_1: P1.8 (DAT1/nIRQ), R1.2, U1.40 (PC9/TIM8_CH4/SDIO_D1)
/SDIO_2: P1.1 (DAT2), R5.2, U1.51 (PC10/UART4_TX/SDIO_D2)
/SDIO_3: P1.2 (DAT3), R4.2, U1.52 (PC11/UART4_RX/SDIO_D3)
/SDIO_CLK: P1.5 (CLK), U1.53 (PC12/UART5_TX/SDIO_CK)
/SDIO_CMD: P1.3 (CMD), R3.2, U1.54 (PD2/TIM3_ETR/UART5_RX/SDIO_CMD)
/VIBRO_ENG: Q6.1 (G), R22.1, U1.16 (USART2_TX/TIM5_CH3/ADC123_IN2/TIM2_CH3/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)
DAC_OUT: R13.2, U1.20 (SPI1_NSS/USART2_CK/DAC_OUT1/ADC12_IN4/P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)
GND: C1.2, C2.2, C3.2, C4.2, C5.2, C6.2, C7.2, C8.1, C9.2, C10.2, C11.2, C12.2, C13.2, C14.2, C16.2, C17.2, C18.1, P1.6 (GND), P2.1, P3.1, P4.1 (GND), P5.4 (GND), P7.1, P10.6, P13.1, P14.1, P18.5 (GND), P19.1, P19.2, P19.3, Q1.1 (G), Q2.2 (S), Q3.2 (S), Q4.2 (S), Q5.2 (S), Q6.2 (S), Q7.2 (S), R6.2, R10.2, R15.2, R17.2, R19.2, R20.2, R22.2, R23.2, U1.12 (VSSA), U1.18 (VSS), U1.31 (VSS), U1.47 (VSS), U1.63 (VSS), U2.2 (GND), U3.2 (Vss), U4.2 (GND), U5.2 (PGND), U5.11 (GND), U5.15 (PGND)
I2C_SCL: P13.3, P14.3, R26.2, U1.29 (I2C2_SCL/USART3_TX/PB10)
I2C_SDA: P13.4, P14.4, R25.2, U1.30 (I2C2_SDA/USART3_RX/PB11)
NRST: P2.2, U1.7 (~NRST)
unnamed: C6.1, U1.5 (PD0/OSC_IN), Y1.2
unnamed: C7.1, U1.6 (PD1/OSC_OUT), Y1.1
unnamed: C17.1, U5.8 (Vref)
unnamed: C18.2, C19.2, R13.1
unnamed: C19.1, R14.2
unnamed: D1.1 (K), R9.2
unnamed: D1.2 (A), P5.1 (VBUS), P18.1 (VBUS), U2.5 (Vbus), U3.4 (Vdd)
unnamed: D2.2 (A), R11.2
unnamed: P3.3, Q1.3 (D)
unnamed: P6.1, U1.8 (PC0/ADC123_IN10)
unnamed: P6.2, U1.9 (PC1/ADC123_IN11)
unnamed: P6.3, U1.10 (PC2/ADC123_IN12)
unnamed: P6.4, U1.11 (PC3/ADC123_IN13)
unnamed: P8.1, U1.14 (WKUP/USART2_CTS/ADC123_IN0/TIM2_CH1_ETR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)
unnamed: P9.1, U1.15 (USART2_RTS/ADC123_IN1/TIM5_CH2/TIM2_CH2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)
unnamed: P11.1, U5.3 (-OutLeft)
unnamed: P11.2, U5.1 (+OutLeft)
unnamed: P12.1, U5.14 (-OutRight)
unnamed: P12.2, U5.16 (+OutRight)
unnamed: P15.1, Q4.3 (D)
unnamed: P16.1, Q6.3 (D)
unnamed: P17.2, R16.1, R18.1, R21.1, R24.1
unnamed: Q2.3 (D), R16.2
unnamed: Q3.3 (D), R18.2
unnamed: Q5.3 (D), R21.2
unnamed: Q7.3 (D), R24.2
unnamed: R9.1, U3.1 (STAT)
unnamed: R10.1, U3.5 (PROG)
unnamed: R14.1, U5.7 (InLeft), U5.10 (InRight)
SWCLK: P2.4, U1.49 (JTCK/SWCLK/PA14)
SWDIO: P2.3, U1.46 (JTMS/SWDIO/PA13)
UART_DBG_TX: D2.1 (K), P7.2, U1.42 (USART1_TX/TIM1_CH2/PA9)
USBDM: P5.2 (D-), P18.2 (D-), U1.44 (USART1_CTS/USBDM/CAN_RX/TIM1_CH4/PA11), U2.4 (I/O3)
USBDP: P5.3 (D+), P18.3 (D+), R8.1, U1.45 (USART1_RTS/USBDP/CAN_TX/TIM1_ETR/PA11), U2.6 (I/O4)
VCC: C8.2, C11.1, C12.1, P13.2, P14.2, P17.1, Q1.2 (S), R7.1, R11.1, R25.1, R26.1, U4.1 (In), U4.3 (Enable), U5.4 (PVDD), U5.5 (~Mute), U5.6 (VDD), U5.12 (~Shutdown), U5.13 (PVDD)
VCC_ADC: C10.1, R6.1, R7.2, U1.24 (PC4/ADC12_IN14)

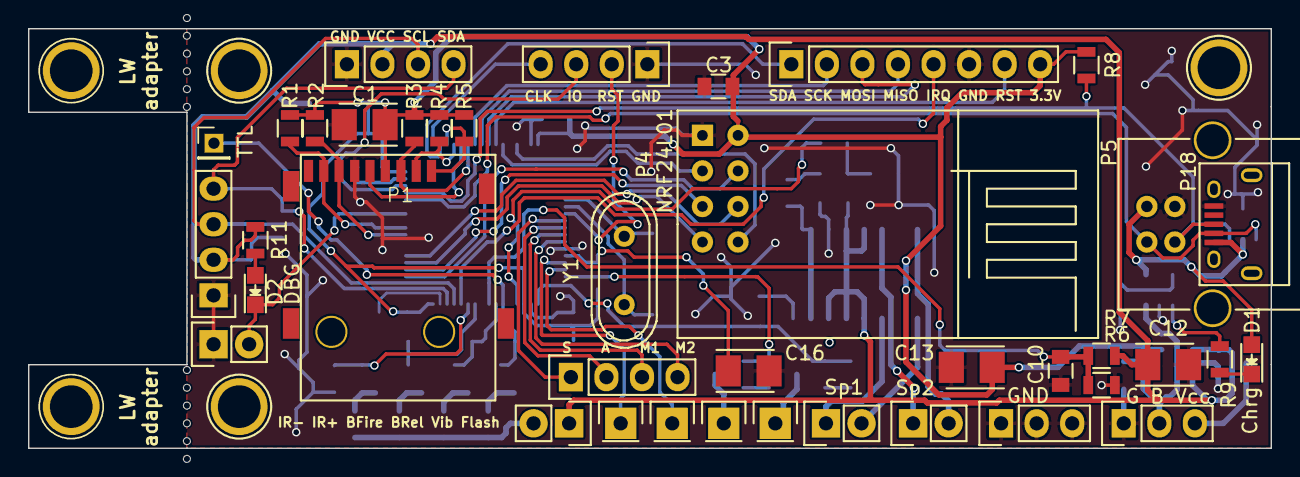
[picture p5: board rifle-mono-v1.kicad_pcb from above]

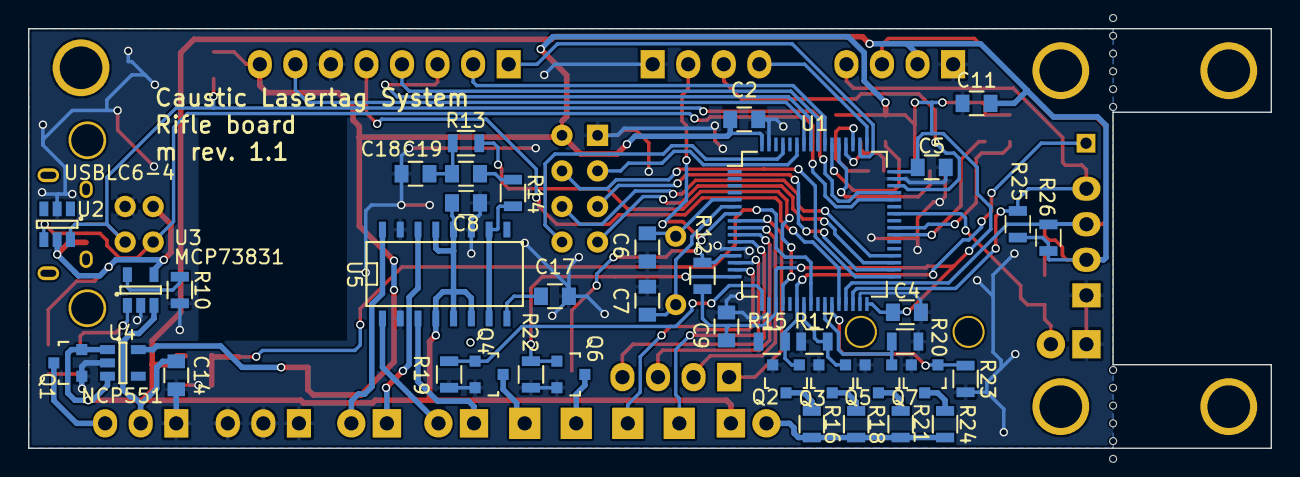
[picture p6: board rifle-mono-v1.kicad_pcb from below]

Board: 2 copper layers, 88.8 x 30.0 mm, 83 parts (40 on the bottom side), 68 nets.

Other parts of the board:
wholes: WHOLES-LINE-3; wholes-line-3
wholes#2, wholes#3, wholes#4: WHOLES-LINE-3; wholes-line-3

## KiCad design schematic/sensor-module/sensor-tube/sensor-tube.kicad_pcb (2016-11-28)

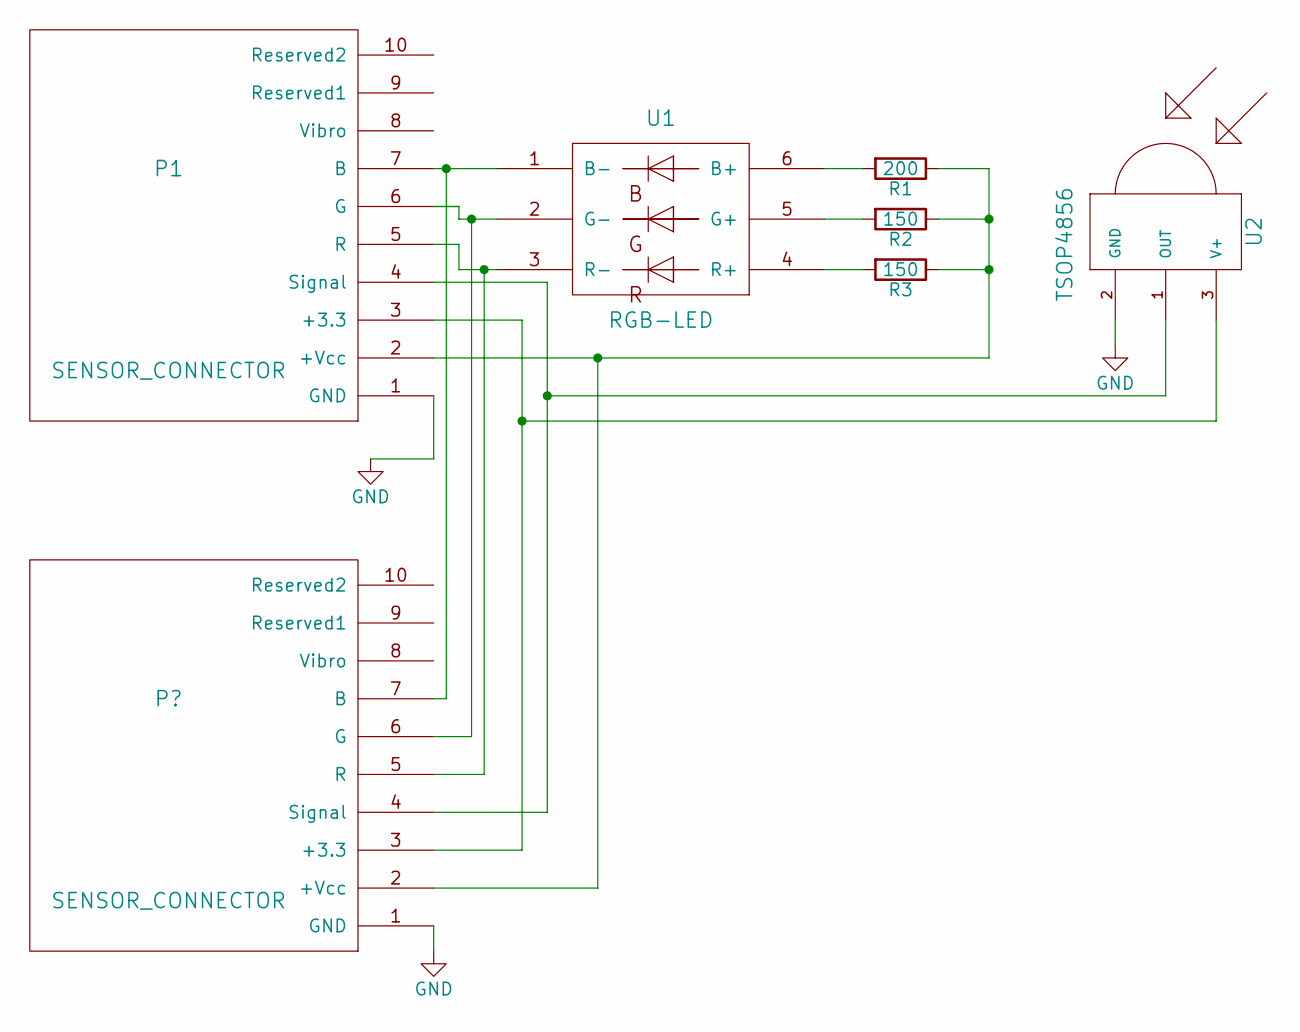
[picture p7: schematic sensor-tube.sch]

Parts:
P1: SENSOR_CONNECTOR
R1: 200
R2, R3: 150
U1: RGB-LED
U2: TSOP4856

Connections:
GND: P1.1 (GND), U2.2 (GND); also elsewhere on the board
unnamed 1: P1.2 (+Vcc), R1.1, R2.1, R3.1; also elsewhere on the board
unnamed 2: P1.3 (+3.3), U2.3 (V+); also elsewhere on the board
unnamed 3: P1.4 (Signal), U2.1 (OUT); also elsewhere on the board
unnamed 4: P1.5 (R), U1.3 (R-); also elsewhere on the board
unnamed 5: P1.6 (G), U1.2 (G-); also elsewhere on the board
unnamed 6: P1.7 (B), U1.1 (B-); also elsewhere on the board
unnamed: R1.2, U1.6 (B+)
unnamed: R2.2, U1.5 (G+)
unnamed: R3.2, U1.4 (R+)

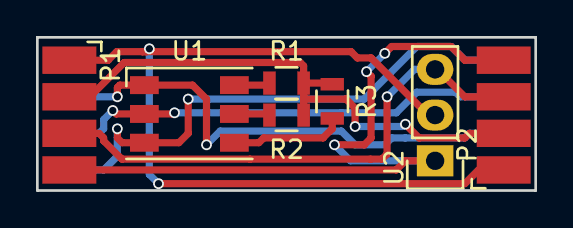
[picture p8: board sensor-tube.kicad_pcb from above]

Board: 2 copper layers, 27.7 x 8.5 mm, 7 parts (0 on the bottom side), 10 nets.

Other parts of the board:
P2: SENSOR_CONNECTOR; caustic-sensors-tube-connector

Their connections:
GND: P2.1; also elsewhere on the board
unnamed 1: P2.2; also elsewhere on the board
unnamed 2: P2.3; also elsewhere on the board
unnamed 3: P2.4; also elsewhere on the board
unnamed 4: P2.5; also elsewhere on the board
unnamed 5: P2.6; also elsewhere on the board
unnamed 6: P2.7; also elsewhere on the board

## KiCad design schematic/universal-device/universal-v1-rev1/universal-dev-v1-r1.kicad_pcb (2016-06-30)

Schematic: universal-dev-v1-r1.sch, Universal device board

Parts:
C1: 4.7uF
C2: 0.47uF
C3: 0.015uF
C4, C5, C6: 0.1uF
C7, C10, C12: CP1
C8: 470uF
C9, C11: 1uF
D1: LED
FB1: FILTER
JP1: JUMPER
K1, K2: CONN_3
K3: TSOP
P1: USB
P2: MCU1
P3: Buttons
P4: VCC
P5: Speaker2
P7: UART1
P8: EXTENSION-CONNECTOR
P9: MOSFET
P10: MCU2
P12: NRF24L01
P13: IR_LED
Q1: MOSFET_P
Q2, Q3, Q5, Q6, Q7, Q8: MOS_N
Q4: MOSFET_N
R1, R3, R4, R5, R8, R9, R12, R13, R14, R15: 10k
R2: 470
R6, R7: R
R10: 1.5k
R11: 2k
U1: PAM8403
U2: NCP551
U3: USBLC6-4
U4: MCP73831

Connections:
+3.3V: C10.1, C12.1, K3.3, P2.2, P8.7, P12.2 (VCC), R10.2, U2.5 (Out)
GND: C3.2, C4.1, C5.2, C6.2, C7.2, C8.2, C9.2, C10.2, C11.2, C12.2, JP1.2, K1.1, K1.2 (PM), K1.3, K2.1, K3.2 (PM), P1.1, P2.1, P7.1, P8.6, Q1.G, Q2.S, Q3.S, Q4.S, Q5.S, Q6.S, Q7.S, Q8.S, R5.2, R8.2, R9.2, R11.2, R12.2, R13.2, R14.2, R15.2, U1.2 (PGND), U1.9 (NC), U1.11 (GND), U1.15 (PGND), U2.2 (GND), U3.2 (GND), U4.2 (Vss)
unnamed: C2.2, R3.1
unnamed: P2.6, P3.3
unnamed: P2.5, P3.2
unnamed: P2.4, P3.1
unnamed: P5.2 (PM), U1.16 (+OutRight)
unnamed: P5.1, U1.14 (-OutRight)
unnamed: P2.7, P3.4
unnamed: R3.2, U1.10 (InRight)
unnamed: P2.12, R1.2
unnamed: P2.14, Q2.G, R12.1
unnamed: P13.1, R6.2, R7.2
unnamed: Q3.D, R7.1
unnamed: Q2.D, R6.1
unnamed: C2.1, C3.1, R1.1
unnamed: P10.19, P12.8 (IRQ)
unnamed: C4.2, U1.8 (Vref)
unnamed: D1.1 (A), P1.4, U3.5 (Vbus), U4.4 (Vdd)
unnamed: C1.1, K2.2 (PM), U4.3 (Vbat)
unnamed: C1.2, R11.1, U4.5 (PROG)
unnamed: R2.2, U4.1 (STAT)
unnamed: D1.2 (K), R2.1
unnamed: K2.3, Q1.D
unnamed: P2.15, Q3.G, R13.1
unnamed: C8.1, C9.1, C11.1, FB1.1, U1.4 (PVDD), U1.5 (~Mute), U1.6 (VDD), U1.12 (~Shutdown), U1.13 (PVDD)
unnamed: P9.1, Q8.D
unnamed: P9.2, Q7.D
unnamed: P9.3, Q6.D
unnamed: P9.4, Q5.D
unnamed: P2.18, Q6.G, R9.1
unnamed: P10.7, Q4.G
unnamed: P2.17, Q5.G, R8.1
unnamed: P2.20, Q8.G, R15.1
unnamed: K3.1, P2.8
unnamed: P2.19, Q7.G, R14.1
unnamed: P8.5, P10.17
unnamed: P8.1, P10.13
unnamed: P8.2, P10.14
unnamed: P8.3, P10.16
unnamed: P8.4, P10.15
unnamed: P10.18, P12.3 (CE)
unnamed: P10.3, P12.4 (CSN)
unnamed: P10.4, P12.5 (SCK)
unnamed: P10.6, P12.6 (MOSI)
unnamed: P10.5, P12.7 (MISO)
unnamed: JP1.1, P12.1 (GND), Q4.D
unnamed: P8.10, P10.2
unnamed: P8.9, P10.1
unnamed: P8.8, P10.20
unnamed: P7.2 (PM), P10.9
unnamed: P1.2, P10.11, U3.6 (I/O4)
unnamed: C6.1, P2.16, R4.2, R5.1
unnamed: P1.3, P10.12, R10.1, U3.4 (I/O3)
VCC: C5.1, C7.1, FB1.2, P4.1, P4.2 (PM), P13.2 (PM), Q1.S, R4.1, U2.1 (In), U2.3 (Enable)

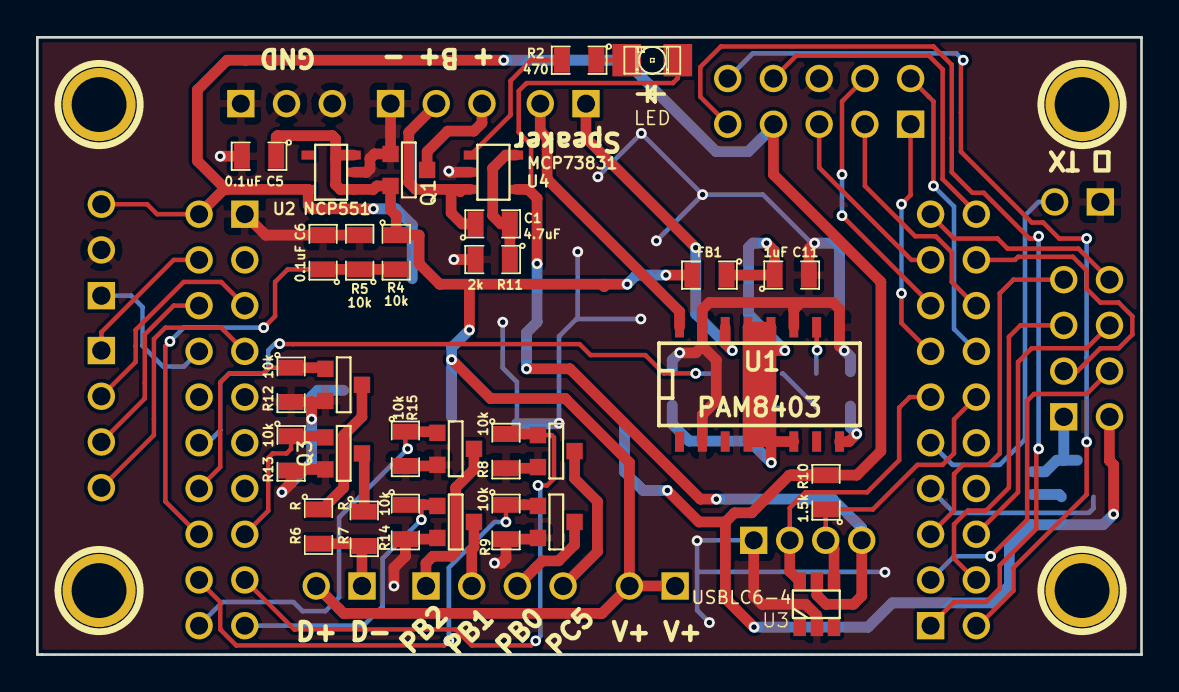
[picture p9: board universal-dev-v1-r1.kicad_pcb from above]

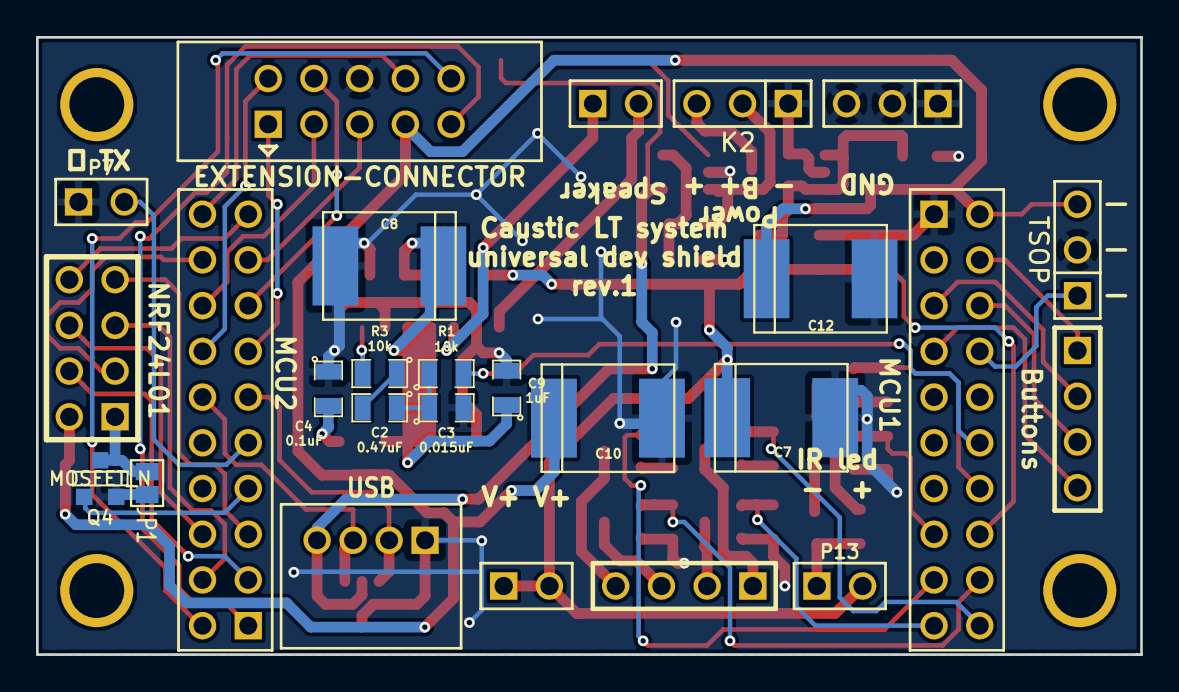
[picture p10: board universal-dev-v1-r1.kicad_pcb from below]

Board: 2 copper layers, 61.3 x 34.3 mm, 60 parts (26 on the bottom side), 55 nets.

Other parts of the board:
1PIN, 1PIN#2, 1PIN#3, 1PIN#4: P***; 1pin

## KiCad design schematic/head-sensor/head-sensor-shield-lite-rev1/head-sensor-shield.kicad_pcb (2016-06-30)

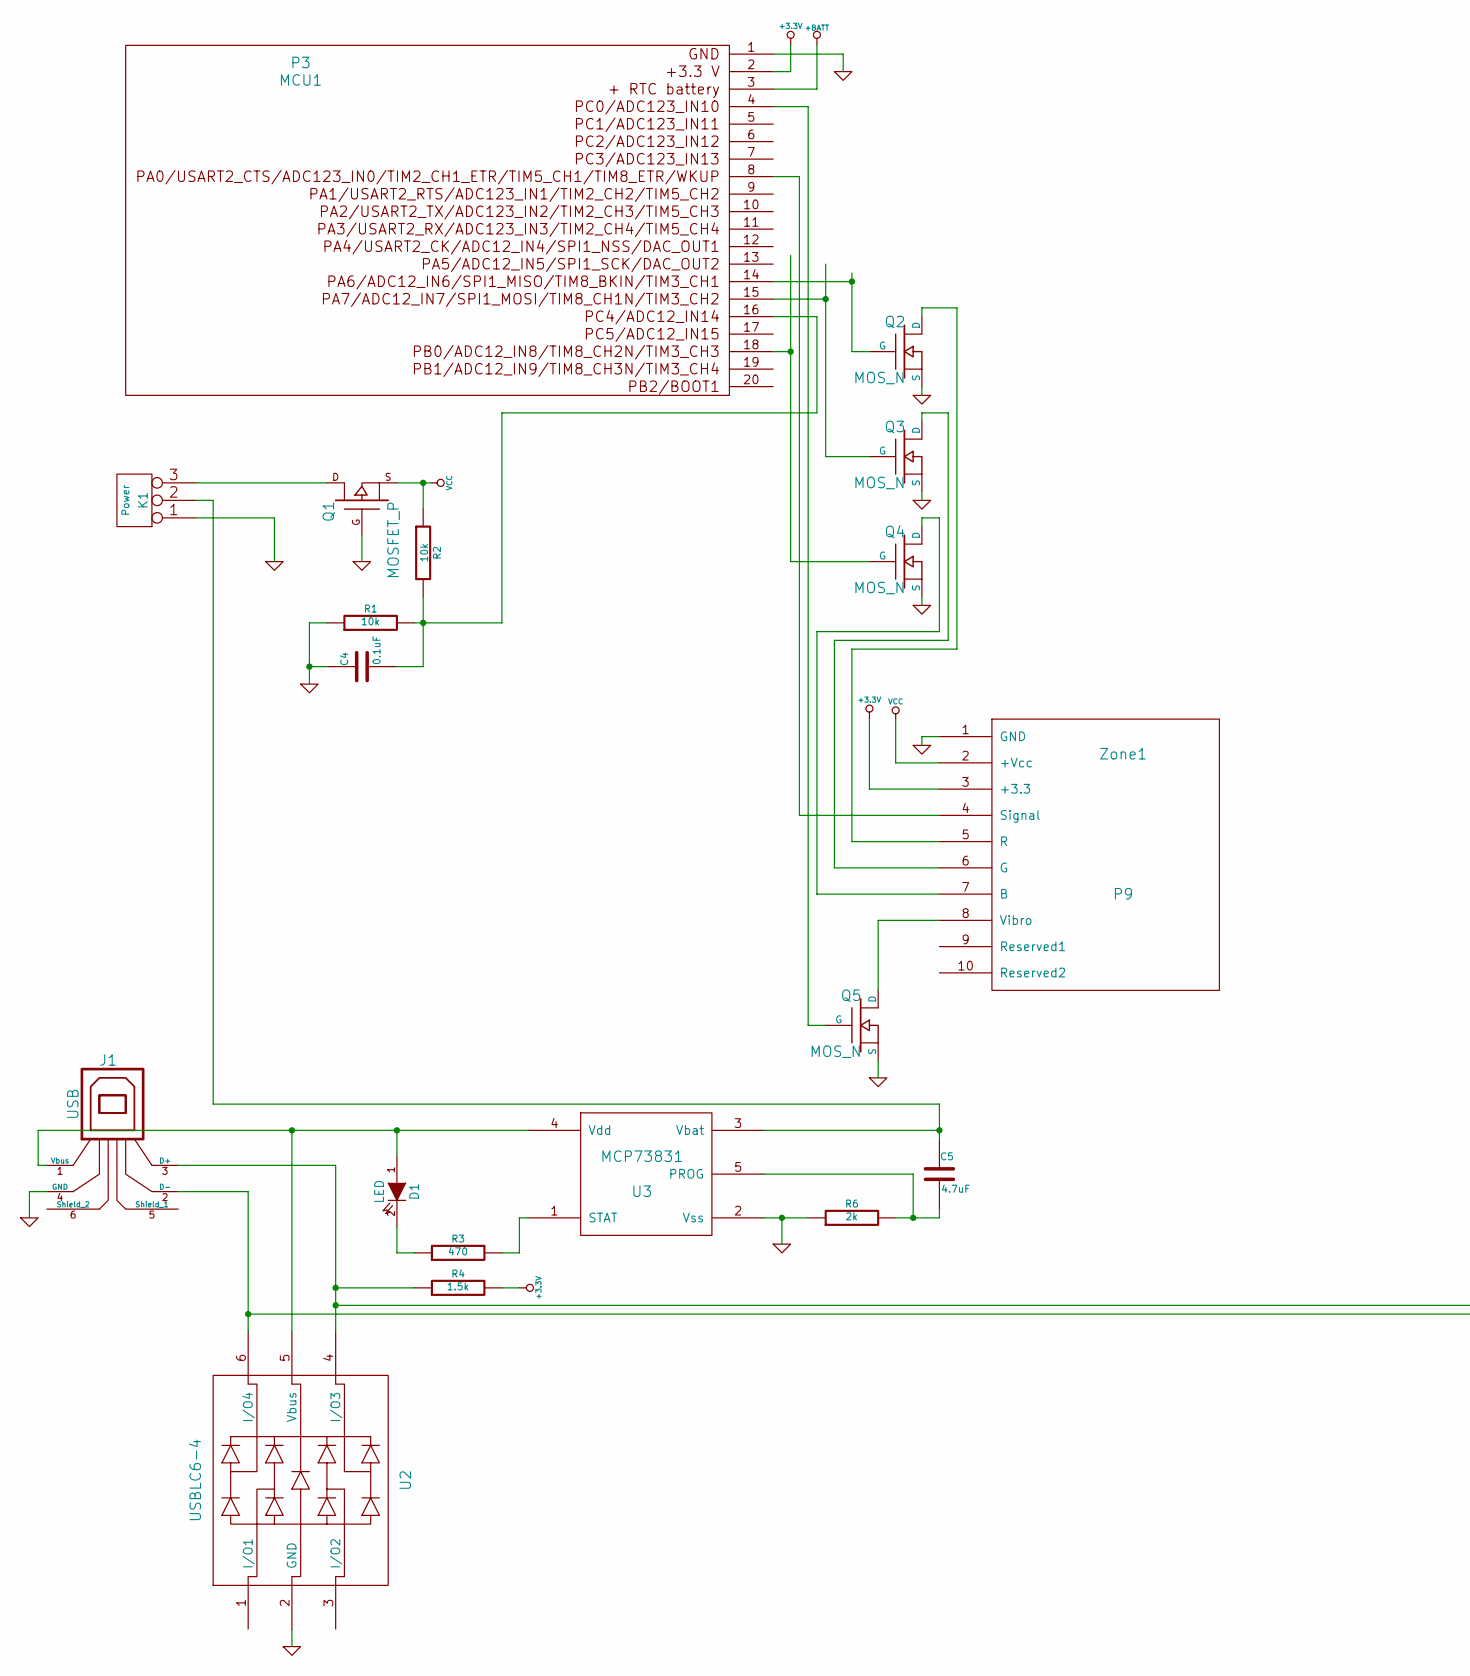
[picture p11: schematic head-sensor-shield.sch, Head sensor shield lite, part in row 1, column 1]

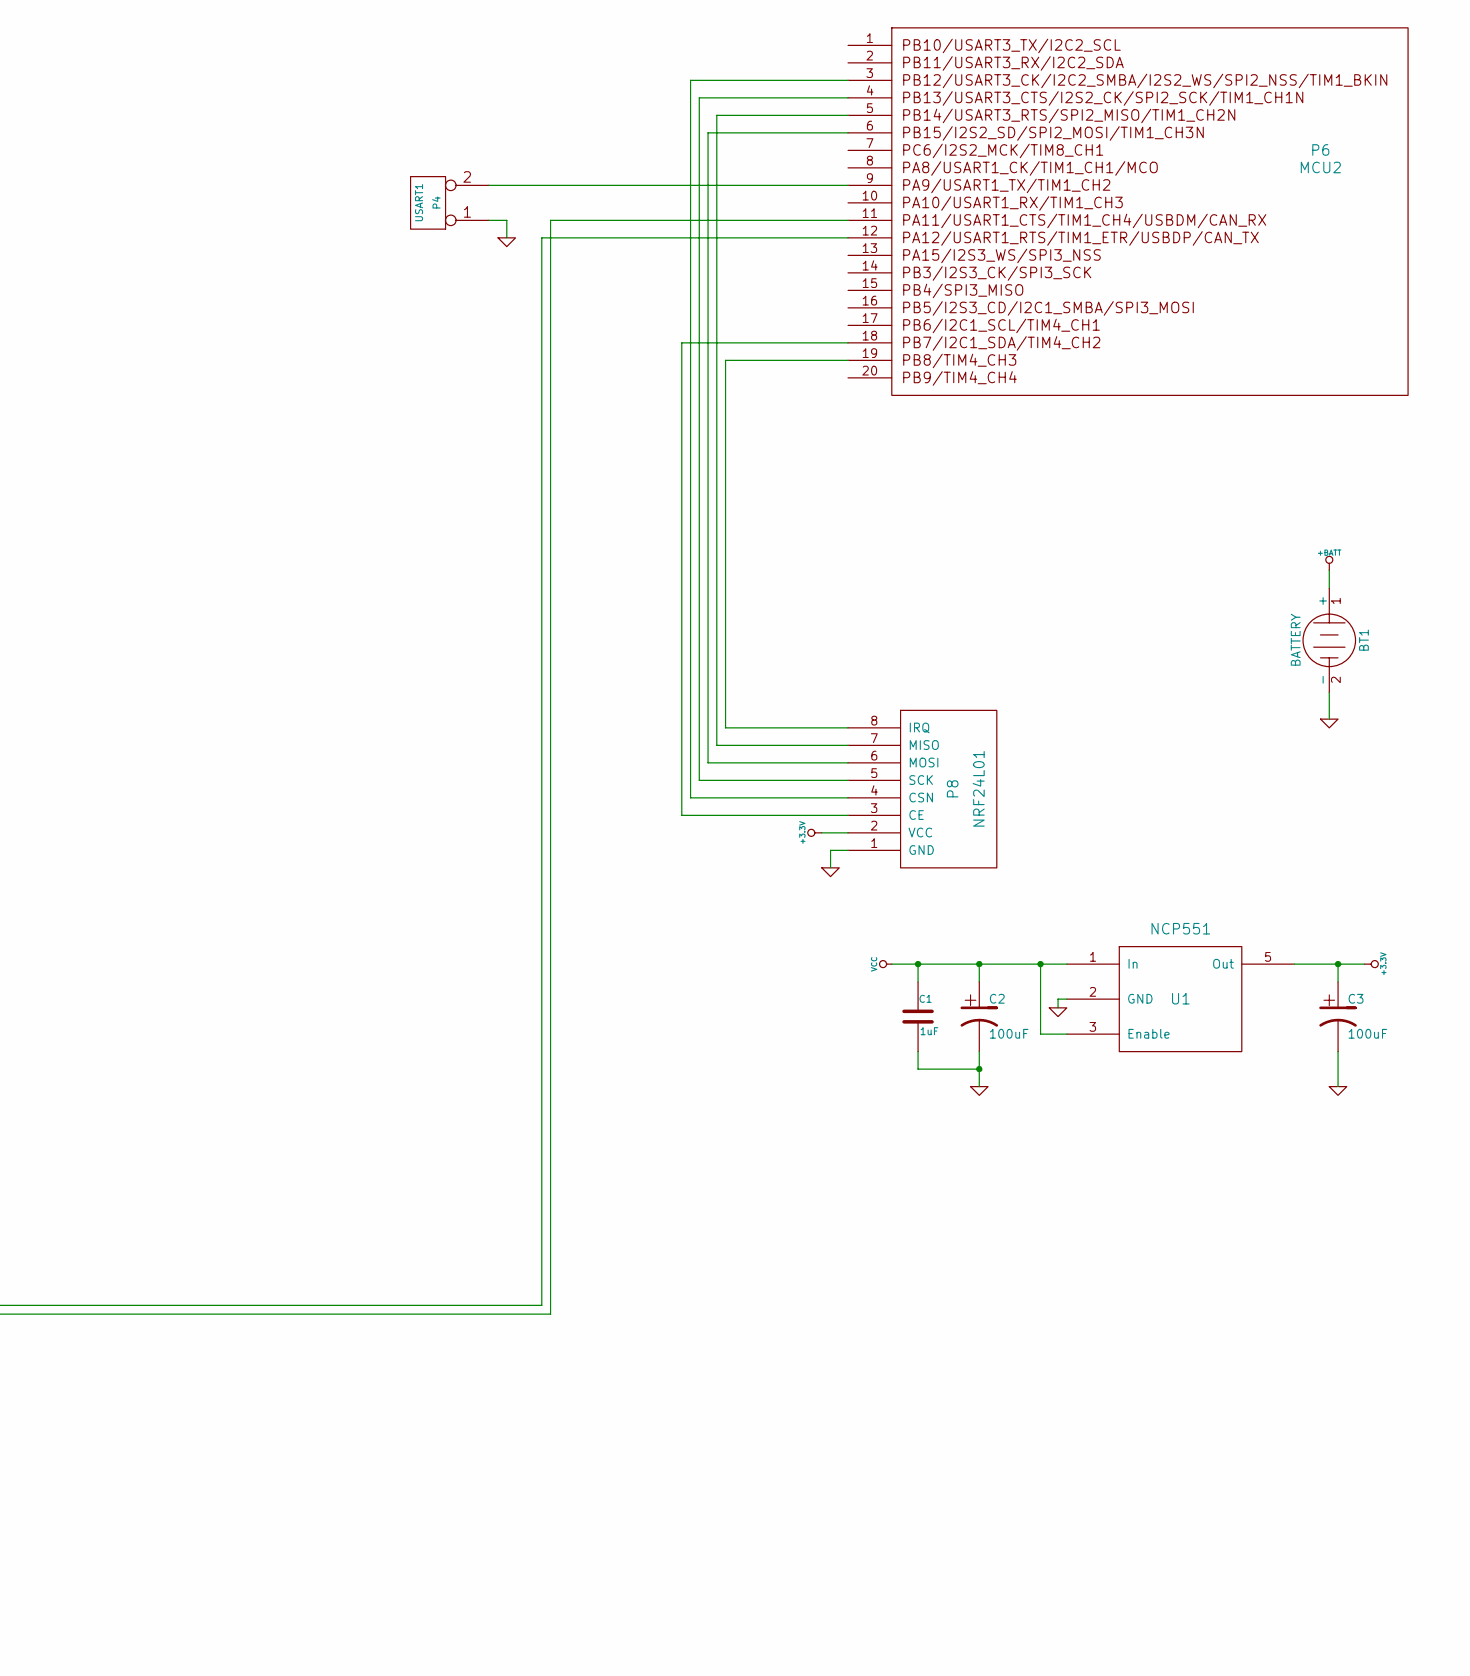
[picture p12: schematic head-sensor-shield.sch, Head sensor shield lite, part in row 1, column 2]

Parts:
BT1: BATTERY
C1: 1uF
C2, C3: 100uF
C4: 0.1uF
C5: 4.7uF
D1: LED
J1: USB
K1: Power
P3: MCU1
P4: USART1
P6: MCU2
P8: NRF24L01
P9: Zone1
Q1: MOSFET_P
Q2, Q3, Q4, Q5: MOS_N
R1, R2: 10k
R3: 470
R4: 1.5k
R6: 2k
U1: NCP551
U2: USBLC6-4
U3: MCP73831

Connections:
+3.3V: C3.1, P3.2, P8.2 (VCC), P9.3 (+3.3), R4.2, U1.5 (Out)
+BATT: BT1.1 (+), P3.3
GND: BT1.2 (-), C1.2, C2.2, C3.2, C4.1, J1.4 (GND), K1.1, P3.1, P4.1, P8.1 (GND), P9.1 (GND), Q1.G, Q2.S, Q3.S, Q4.S, Q5.S, R1.1, R6.1, U1.2 (GND), U2.2 (GND), U3.2 (Vss)
unnamed: K1.3, Q1.D
unnamed: P9.7 (B), Q4.D
unnamed: P3.8, P9.4 (Signal)
unnamed: P9.5 (R), Q2.D
unnamed: P9.6 (G), Q3.D
unnamed: P3.18, Q4.G
unnamed: P3.15, Q3.G
unnamed: P3.14, Q2.G
unnamed: P6.5, P8.7 (MISO)
unnamed: P6.3, P8.4 (CSN)
unnamed: P6.4, P8.5 (SCK)
unnamed: P6.6, P8.6 (MOSI)
unnamed: P6.19, P8.8 (IRQ)
unnamed: P6.18, P8.3 (CE)
unnamed: J1.2 (D-), P6.11, U2.6 (I/O4)
unnamed: J1.3 (D+), P6.12, R4.1, U2.4 (I/O3)
unnamed: C5.1, K1.2 (PM), U3.3 (Vbat)
unnamed: C5.2, R6.2, U3.5 (PROG)
unnamed: P4.2 (PM), P6.9
unnamed: P3.4, Q5.G
unnamed: P9.8 (Vibro), Q5.D
unnamed: R3.2, U3.1 (STAT)
unnamed: D1.2 (K), R3.1
unnamed: D1.1 (A), J1.1 (Vbus), U2.5 (Vbus), U3.4 (Vdd)
unnamed: C4.2, P3.16, R1.2, R2.2
VCC: C1.1, C2.1, P9.2 (+Vcc), Q1.S, R2.1, U1.1 (In), U1.3 (Enable)

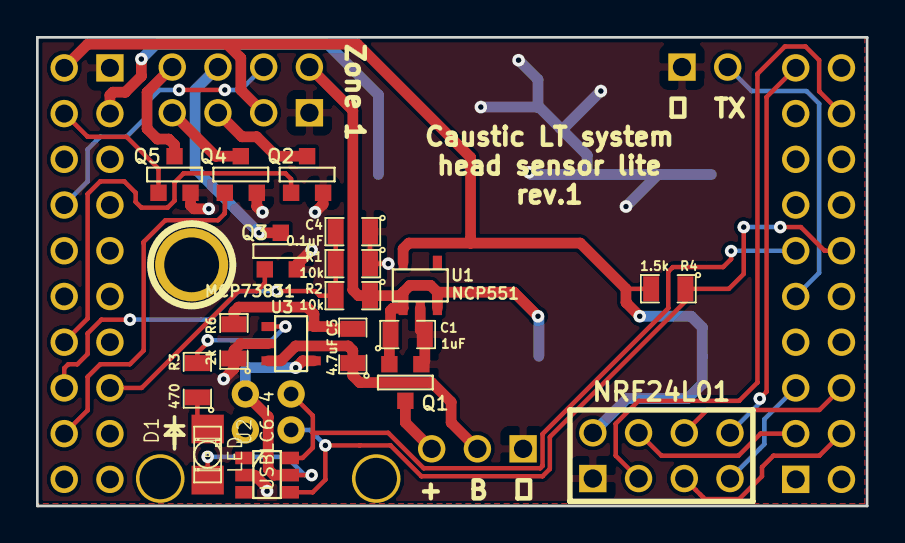
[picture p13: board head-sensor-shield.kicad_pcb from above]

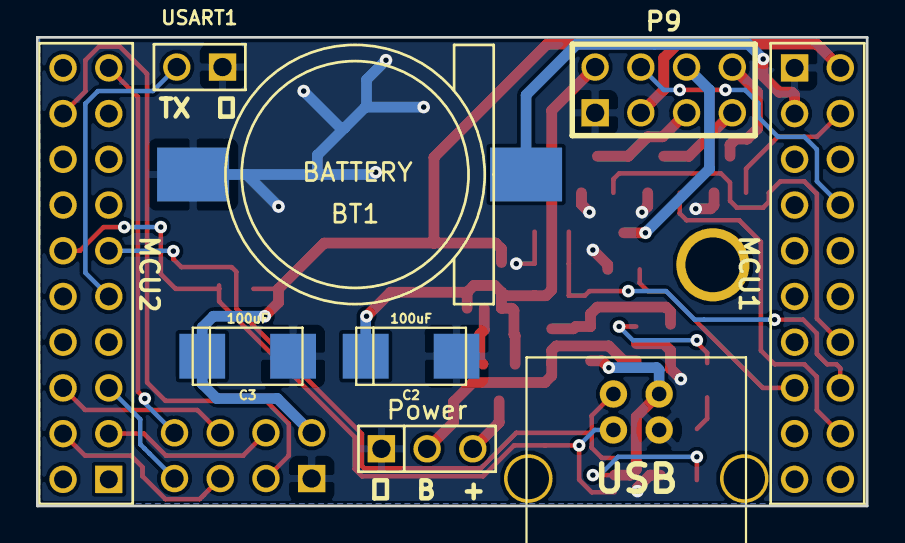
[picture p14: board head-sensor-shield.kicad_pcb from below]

Board: 2 copper layers, 46.1 x 26.0 mm, 28 parts (9 on the bottom side), 29 nets.

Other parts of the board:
1PIN: P***; 1pin

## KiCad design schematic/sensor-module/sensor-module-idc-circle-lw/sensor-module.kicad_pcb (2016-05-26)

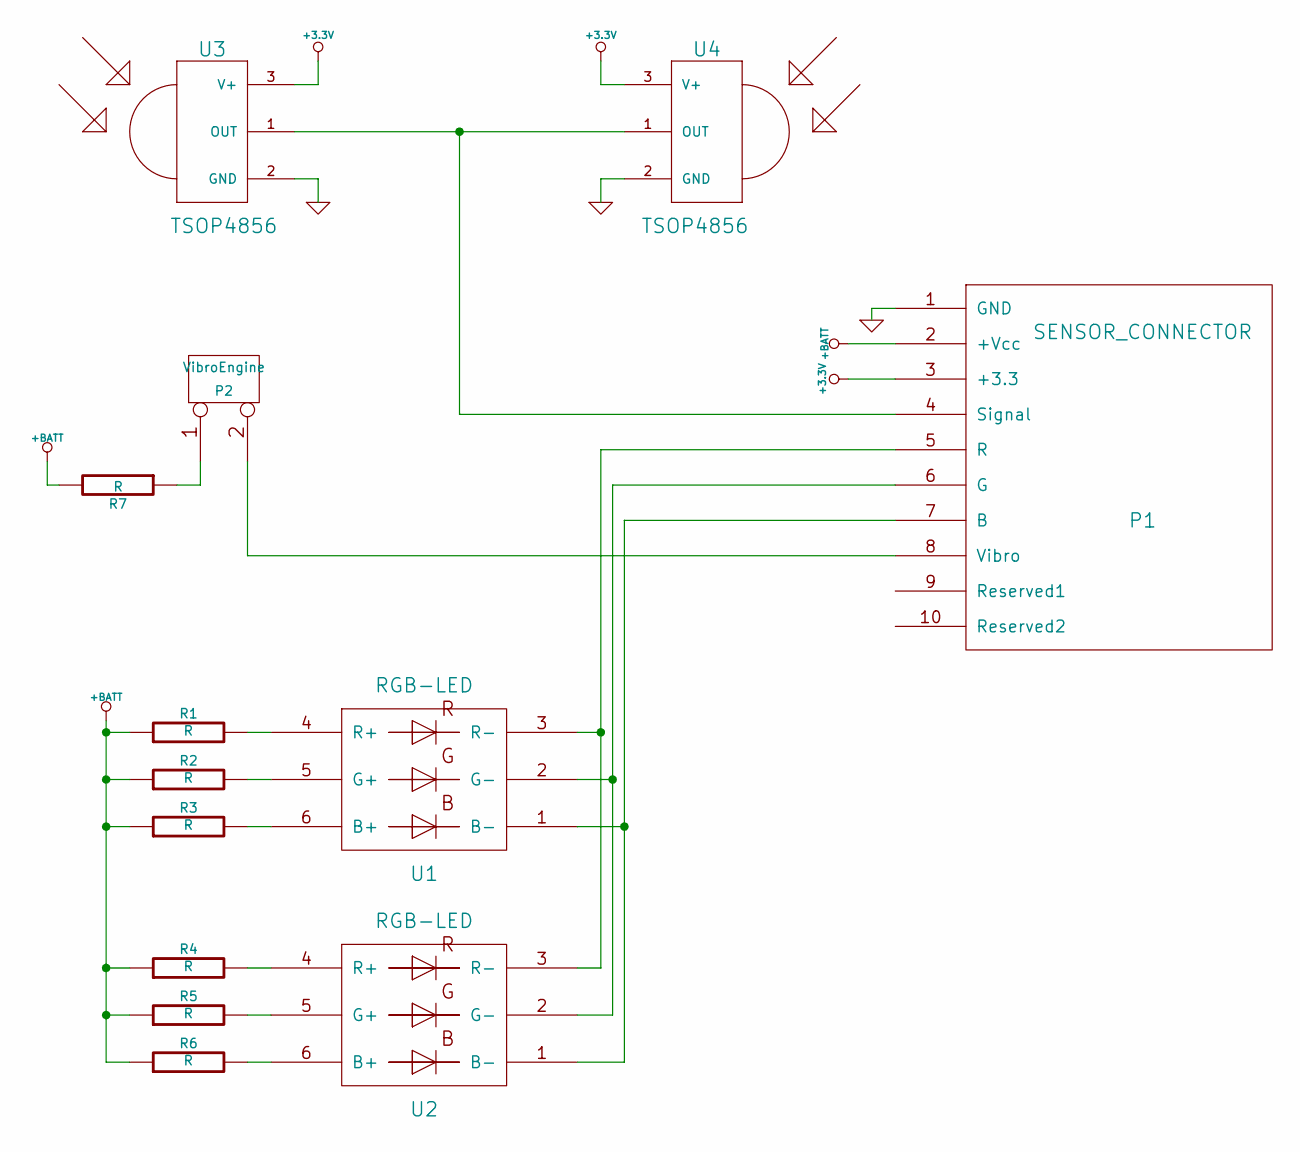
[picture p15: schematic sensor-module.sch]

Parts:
P1: SENSOR_CONNECTOR
P2: VibroEngine
R1, R2, R3, R4, R5, R6, R7: R
U1, U2: RGB-LED
U3, U4: TSOP4856

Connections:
+3.3V: P1.3 (+3.3), U3.3 (V+), U4.3 (V+)
+BATT: P1.2 (+Vcc), R1.1, R2.1, R3.1, R4.1, R5.1, R6.1, R7.2
GND: P1.1 (GND), U3.2 (GND), U4.2 (GND)
unnamed: P1.4 (Signal), U3.1 (OUT), U4.1 (OUT)
unnamed: R6.2, U2.6 (B+)
unnamed: R5.2, U2.5 (G+)
unnamed: R4.2, U2.4 (R+)
unnamed: P1.8 (Vibro), P2.2 (PM)
unnamed: P2.1, R7.1
unnamed: P1.5 (R), U1.3 (R-), U2.3 (R-)
unnamed: P1.6 (G), U1.2 (G-), U2.2 (G-)
unnamed: P1.7 (B), U1.1 (B-), U2.1 (B-)
unnamed: R1.2, U1.4 (R+)
unnamed: R3.2, U1.6 (B+)
unnamed: R2.2, U1.5 (G+)

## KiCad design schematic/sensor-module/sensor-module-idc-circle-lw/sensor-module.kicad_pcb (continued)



Board: 2 copper layers, 29.5 x 29.5 mm, 15 parts (8 on the bottom side), 15 nets.

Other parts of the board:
1PIN, 1PIN#2: P***; 1pin

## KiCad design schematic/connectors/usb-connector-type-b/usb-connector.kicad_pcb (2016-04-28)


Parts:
J1: USB
P1: CONN_4

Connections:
unnamed: J1.4 (GND), P1.1
unnamed: J1.1 (Vbus), P1.4
unnamed: J1.3 (D+), P1.3
unnamed: J1.2 (D-), P1.2


Board: 2 copper layers, 25.7 x 13.5 mm, 4 parts (0 on the bottom side), 4 nets.

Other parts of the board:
1PIN, 1PIN#2: P***; 1pin

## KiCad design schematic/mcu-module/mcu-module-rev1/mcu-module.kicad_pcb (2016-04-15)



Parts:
C1, C6: 100uF
C2, C3, C4, C5: 20pF
C7, C8, C9, C10: 0.1uF
FB1: FILTER
P1: MCU1
P2: MICROSD-SDIO-CD
P3: SWD
P4: MCU2
R1, R2, R3, R4, R5: 47k
R6: 100
U1: STM32F103RE; LQFP64
X1: 32768Hz
X2: 8MHz

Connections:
+3.3V: C1.1, C7.1, C8.1, C9.1, C10.1, FB1.2, P2.4 (Vdd), R1.2, R2.2, R3.2, R4.2, R5.2, R6.2, U1.19 (VDD), U1.32 (VDD), U1.48 (VDD), U1.64 (VDD)
GND: C1.2, C2.1, C3.1, C4.1, C5.1, C6.2, C7.2, C8.2, C9.2, C10.2, P1.1, P2.6 (GND), P2.CD1, P3.1, U1.12 (VSSA), U1.18 (VSS), U1.31 (VSS), U1.47 (VSS), U1.63 (VSS)
unnamed: P1.18, U1.26 (ADC12_IN8/TIM3_CH3/TIM8_CH2N/PB0)
unnamed: P1.20, U1.28 (BOOT1/PB2)
unnamed: P1.19, U1.27 (ADC12_IN9/TIM3_CH4/TIM8_CH3N/PB1)
unnamed: P1.17, U1.25 (PC5/ADC12_IN15)
unnamed: P1.16, U1.24 (PC4/ADC12_IN14)
unnamed: P4.9, U1.42 (USART1_TX/TIM1_CH2/PA9)
unnamed: P4.8, U1.41 (USART1_CK/TIM1_CH1/MCO/PA8)
unnamed: P4.7, U1.37 (PC6/I2S2_MCK/TIM8_CH1/SDIO_D6)
unnamed: P4.6, U1.36 (SPI2_MOSI/I2S2_SD/TIM1_CH3N/PB15)
unnamed: P4.5, U1.35 (SPI2_MISO/TIM1_CH2N/USART3_RTS/PB14)
unnamed: P4.4, U1.34 (SPI2_SCK/I2S2_CK/USART3_CTS/TIM1_CH1N/P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)
unnamed: P4.3, U1.33 (SPI2_NSS/I2S2_WS/I2C2_SMBA/USART3_CK/TI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)
unnamed: P4.2, U1.30 (I2C2_SDA/USART3_RX/PB11)
unnamed: P4.1, U1.29 (I2C2_SCL/USART3_TX/PB10)
unnamed: P1.6, U1.10 (PC2/ADC123_IN12)
unnamed: P1.10, U1.16 (USART2_TX/TIM5_CH3/ADC123_IN2/TIM2_CH3/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)
unnamed: P1.9, U1.15 (USART2_RTS/ADC123_IN1/TIM5_CH2/TIM2_CH2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)
unnamed: P1.8, U1.14 (WKUP/USART2_CTS/ADC123_IN0/TIM2_CH1_ETR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)
unnamed: P1.7, U1.11 (PC3/ADC123_IN13)
unnamed: P1.5, U1.9 (PC1/ADC123_IN11)
unnamed: P1.4, U1.8 (PC0/ADC123_IN10)
unnamed: P1.3, U1.1 (VBAT)
unnamed: P1.14, U1.22 (SPI1_MISO/TIM8_BKIN/ADC12_IN6/TIM3_CH1/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)
unnamed: P1.15, U1.23 (SPI1_MOSI/TIM8_CH1N/ADC12_IN7/TIM3_CH2/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)
unnamed: P1.13, U1.21 (SPI1_SCK/DAC_OUT2/ADC12_IN5/PA5)
unnamed: P1.11, U1.17 (USART2_RX/TIM5_CH4/ADC123_IN3/TIM2_CH4/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)
unnamed: P1.12, U1.20 (SPI1_NSS/USART2_CK/DAC_OUT1/ADC12_IN4/P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)
unnamed: FB1.1, P1.2
unnamed: P4.19, U1.61 (TIM4_CH3/SDIO_D4/PB8)
unnamed: P4.18, U1.59 (I2C1_SDA/TIM4_CH2/PB7)
unnamed: P4.17, U1.58 (I2C1_SCL/TIM4_CH1/PB6)
unnamed: P4.16, U1.57 (I2C1_SMBA/SPI3_MOSI/I2S3_CD/PB5)
unnamed: P4.13, U1.50 (JTDI/SPI3_NSS/I2S3_WS/PA15)
unnamed: P4.12, U1.45 (USART1_RTS/USBDP/CAN_TX/TIM1_ETR/PA11)
unnamed: P4.11, U1.44 (USART1_CTS/USBDM/CAN_RX/TIM1_CH4/PA11)
unnamed: P4.10, U1.43 (USART1_RX/TIM1_CH3/PA10)
unnamed: P3.2, U1.7 (~NRST)
unnamed: P4.15, U1.56 (NJTRST/SPI3_MISO/PB4)
unnamed: P4.20, U1.62 (TIM4_CH4/SDIO_D5/PB9)
unnamed: P4.14, U1.55 (JTDO/SPI3_SCK/I2S3_CK/PB3)
unnamed: P3.3, U1.46 (JTMS/SWDIO/PA13)
unnamed: P3.4, U1.49 (JTCK/SWCLK/PA14)
unnamed: C2.2, U1.3 (PC14/OSC32_IN), X1.1
unnamed: C3.2, U1.4 (PC15/OSC32_OUT), X1.2
unnamed: P2.CD2, U1.38 (PC7/I2S3_MCK/TIM8_CH2/SDIO_D7)
unnamed: C6.1, R6.1, U1.13 (VDDA)
unnamed: C4.2, U1.5 (PD0/OSC_IN), X2.2
unnamed: P2.3 (CMD), R5.1, U1.54 (PD2/TIM3_ETR/UART5_RX/SDIO_CMD)
unnamed: P2.5 (CLK), U1.53 (PC12/UART5_TX/SDIO_CK)
unnamed: C5.2, U1.6 (PD1/OSC_OUT), X2.1
unnamed: P2.7 (DAT0), R4.1, U1.39 (PC8/TIM8_CH3/SDIO_D0)
unnamed: P2.8 (DAT1/nIRQ), R3.1, U1.40 (PC9/TIM8_CH4/SDIO_D1)
unnamed: P2.1 (DAT2), R2.1, U1.51 (PC10/UART4_TX/SDIO_D2)
unnamed: P2.2 (DAT3), R1.1, U1.52 (PC11/UART4_RX/SDIO_D3)



Board: 2 copper layers, 46.2 x 26.0 mm, 24 parts (12 on the bottom side), 56 nets.

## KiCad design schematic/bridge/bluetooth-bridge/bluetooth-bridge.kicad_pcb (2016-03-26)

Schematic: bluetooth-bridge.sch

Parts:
C1, C2, C3, C5: 0.1uF
C4, C6, C7: 100uF
C8: 0.1
C9: 47uF
D1, D2, D3: LED
FB1, FB2: FILTER
K1: Battery
P1: MCU1
P2: USART1
P3: USB
P4: MCU2
P5: EXTENSION-CONNECTOR
P6: NRF24L01
Q1: MOSFET_P
R1, R2, R3: 10k
R4, R5, R7: 470
R6: 1.5k
R8: 2k
U1: ITEAD_HC-05
U2: NCP551
U3: USBLC6-4
U4: MCP73831

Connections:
+3.3V: C5.1, C6.1, FB1.1, FB2.2, P1.2, P5.7, R6.1, U2.5 (Out)
GND: C1.2, C2.2, C3.2, C4.2, C5.2, C6.2, C7.2, C8.2, D1.2 (K), D2.2 (K), K1.1, P1.1, P2.1, P3.1, P5.6, P6.1 (GND), Q1.G, R2.2, R3.2, R8.1, U1.13 (GND), U1.21 (GND), U1.22 (GND), U2.2 (GND), U3.2 (GND), U4.2 (Vss)
unnamed: P4.13, P5.1
unnamed: P4.14, P5.2
unnamed: P4.16, P5.3
unnamed: P4.15, P5.4
unnamed: P4.17, P5.5
unnamed: P4.1, P5.9
unnamed: P4.2, P5.10
unnamed: P4.19, P6.8 (IRQ)
unnamed: P4.18, P6.3 (CE)
unnamed: P4.3, P6.4 (CSN)
unnamed: P4.4, P6.5 (SCK)
unnamed: P4.6, P6.6 (MOSI)
unnamed: P4.5, P6.7 (MISO)
unnamed: P2.2 (PM), P4.9
unnamed: P4.20, P5.8
unnamed: P3.2, P4.11, U3.6 (I/O4)
unnamed: P3.3, P4.12, R6.2, U3.4 (I/O3)
unnamed: D2.1 (A), R5.2
unnamed: R5.1, U1.32 (PIO9)
unnamed: D1.1 (A), R4.2
unnamed: R4.1, U1.24 (PIO1)
unnamed: P1.11, U1.1 (UART_TX)
unnamed: P1.10, U1.2 (UART_RX)
unnamed: R3.1, U1.26 (PIO3), U1.34 (PIO11)
unnamed: C7.1, C8.1, FB2.1, P6.2 (VCC)
unnamed: C3.1, C4.1, FB1.2, U1.12 (VCC)
unnamed: C9.1, K1.2 (PM), U4.3 (Vbat)
unnamed: K1.3, Q1.D
unnamed: R7.1, U4.1 (STAT)
unnamed: C9.2, R8.2, U4.5 (PROG)
unnamed: D3.2 (K), R7.2
unnamed: D3.1 (A), P3.4, U3.5 (Vbus), U4.4 (Vdd)
unnamed: C1.1, Q1.S, R1.1, U2.1 (In), U2.3 (Enable)
unnamed: C2.1, P1.16, R1.2, R2.1



Board: 2 copper layers, 47.5 x 42.2 mm, 36 parts (11 on the bottom side), 36 nets.

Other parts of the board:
1PIN, 1PIN#2: P***; 1pin

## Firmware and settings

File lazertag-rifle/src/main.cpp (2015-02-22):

//
// This file is part of the GNU ARM Eclipse distribution.
// Copyright (c) 2014 Liviu Ionescu.
//

// ----------------------------------------------------------------------------

#include <stdio.h>
#include "diag/Trace.h"

#include "logic/rifle.hpp"
#include "logic/head-sensor.hpp"
#include "hal/usart.hpp"
#include "hw/sdcard.h"
#include "dev/console.hpp"
#include "dev/alive-indicator.hpp"
#include "dev/buttons.hpp"
#include "dev/wav-player.hpp"
#include "hal/system-clock.hpp"
#include "hal/leds.hpp"
#include "core/scheduler.hpp"
#include "core/memory-utils.h"

#include "tests/console-tester.hpp"
#include <functional>
#include <vector>

//#undef DEVICE_RIFLE

//#ifndef DEVICE_RIFLE
//#define DEVICE_HEAD_SENSOR
//#endif

// ----------------------------------------------------------------------------
//
// The external clock frequency is specified as a preprocessor definition
// passed to the compiler via a command line option (see the 'C/C++ General' ->
// 'Paths and Symbols' -> the 'Symbols' tab, if you want to change it).
// The value selected during project creation was HSE_VALUE=8000000.
//

// Sample pragmas to cope with warnings. Please note the related line at
// the end of this function, used to pop the compiler diagnostics status.
#pragma GCC diagnostic push
#pragma GCC diagnostic ignored "-Wunused-parameter"
#pragma GCC diagnostic ignored "-Wmissing-declarations"
#pragma GCC diagnostic ignored "-Wreturn-type"

char buff[100];

void test(const char* b, int size)
{
	printf("Registered\n");
}

void fireCallbackTest(bool state)
{
	printf("keypressedm state=%d\n", state ? 1 : 0);
}

Rifle *rifle = nullptr;
HeadSensor *headSensor = nullptr;

void checkMemory()
{
	if (isMemoryCorrupted) {
		printf("Memory corrupted!!\n");
	}
}


int main(int argc, char* argv[])
{
	// Send a greeting to the trace device (skipped on Release).
	//trace_puts("Hello ARM World!");

	// The standard output and the standard error should be forwarded to
	// the trace device. For this to work, a redirection in _write.c is
	// required.
	//puts("Standard output message.");
	//fprintf(stderr, "Standard error message.\n");

	// At this stage the system clock should have already been configured
	// at high speed.
	NVIC_PriorityGroupConfig(NVIC_PriorityGroup_4);

	trace_printf("\n\nStarting system...\n", SystemCoreClock);
	trace_printf("System clock: %uHz\n", SystemCoreClock);

	// Perform all necessary initialisations for the LED.

	Console::instance().init(0);

	ConsoleTester tester;

	systemClock->wait_us(100000);

#if defined(DEVICE_RIFLE)
	rifle = new Rifle;
	rifle->configure();
#elif defined(DEVICE_HEAD_SENSOR)
	headSensor = new HeadSensor;
	headSensor->configure();
#else
	#error "Device type not selected!"
#endif

	Scheduler::instance().addTask(std::bind(&Console::interrogate, &Console::instance()), false, 500000);
	Scheduler::instance().addTask(checkMemory, false, 500000);
	Console::instance().prompt();
	WavPlayer::instance();

	Scheduler::instance().mainLoop();

	// Why? - Why not?
#if defined(DEVICE_RIFLE)
	delete rifle;
#elif defined(DEVICE_HEAD_SENSOR)
	delete headSensor;
#endif
}

#pragma GCC diagnostic pop

// ----------------------------------------------------------------------------

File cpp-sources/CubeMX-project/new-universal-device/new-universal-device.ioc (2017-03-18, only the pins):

Mcu.UserName=STM32F103RETx
PA10.Signal=USART1_RX
PA11.Signal=USB_DM
PA12.Signal=USB_DP
PA13.Signal=SYS_JTMS-SWDIO
PA14.Signal=SYS_JTCK-SWCLK
PA2.Signal=USART2_TX
PA3.Signal=USART2_RX
PA4.Signal=COMP_DAC1_group
PA5.Signal=GPXTI5
PA6.Signal=S_TIM3_CH1
PA7.Signal=S_TIM3_CH2
PA9.Signal=USART1_TX
PB0.Signal=S_TIM3_CH3
PB10.Signal=USART3_TX
PB13.Signal=SPI2_SCK
PB14.Signal=SPI2_MISO
PB15.Signal=SPI2_MOSI
PB3.Signal=SPI3_SCK
PB4.Signal=SPI3_MISO
PB5.Signal=SPI3_MOSI
PB8.Signal=GPXTI8
PC0.Signal=GPXTI0
PC1.Signal=GPXTI1
PC10.Signal=SDIO_D2
PC11.Signal=SDIO_D3
PC12.Signal=SDIO_CK
PC13-TAMPER-RTC.Signal=GPXTI13
PC14-OSC32_IN.Signal=GPXTI14
PC15-OSC32_OUT.Signal=GPXTI15
PC2.Signal=GPXTI2
PC3.Signal=GPXTI3
PC4.Signal=ADCx_IN14
PC6.Signal=GPXTI6
PC7.Signal=GPXTI7
PC8.Signal=SDIO_D0
PC9.Signal=SDIO_D1
PD0-OSC_IN.Signal=RCC_OSC_IN
PD1-OSC_OUT.Signal=RCC_OSC_OUT
PD2.Signal=SDIO_CMD

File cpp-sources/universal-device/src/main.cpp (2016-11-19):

/*
*    Copyright (C) 2016 by Aleksey Bulatov
*
*    This file is part of Caustic Lasertag System project.
*
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
*    @license GPL-3.0+ <http://spdx.org/licenses/GPL-3.0+>
*/

#include "core/debug-settings.hpp"
#include "core/device-initializer.hpp"
#include "core/diagnostic.hpp"
#include "core/logging.hpp"
#include "core/os-wrappers.hpp"
#include "core/power-monitor.hpp"
#include "dev/wav-player.hpp"
#include "hal/adc.hpp"
#include "hal/rtc.hpp"
#include "head-sensor/head-sensor.hpp"

#include <functional>
#include <stdio.h>

DeviceInitializer deviceInitializer;

IADC* adc = nullptr;

TaskOnce sound([](){
	info << "Sound here";

	//WavPlayer::instance().play("piknik.wav", 1);
	//WavPlayer::instance().play("sine.wav", 0);
});

int main(void)
{
	deviceInitializer.initEnvironment();

#ifdef DEBUG
	debug.enable();
#ifndef DBG_RADIO_DISABLE
	radio.enable();
#endif
	//trace.enable();
#endif
	info << "=============== Device initialization ===============";

	sound.setStackSize(128);
	//sound.run(2000);

	IAnyDevice* device = deviceInitializer.initDevice("device.ini");

	SystemMonitor::instance().run();

	//HAL_Delay(10);

	Kernel::instance().run();


	// We should never get here as control is now taken by the scheduler
	while (1)
	{
		printf("That's fail\n");
	}
}

char buf[10];


#ifdef USE_FULL_ASSERT

extern "C" void assert_failed(uint8_t* file, uint32_t line)
{
	//error << "Called assert_failed at " << (char*)file << ":" << (int)line;
}

#endif

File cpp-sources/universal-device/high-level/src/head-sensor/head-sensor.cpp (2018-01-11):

/*
*    Copyright (C) 2016 by Aleksey Bulatov
*
*    This file is part of Caustic Lasertag System project.
*
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
*    @license GPL-3.0+ <http://spdx.org/licenses/GPL-3.0+>
*/


#include "core/device-initializer.hpp"
#include "core/diagnostic.hpp"
#include "core/logging.hpp"
#include "core/os-wrappers.hpp"
#include "core/power-monitor.hpp"
#include "dev/nrf24l01.hpp"
#include "bluetooth-bridge/bluetooth-bridge.hpp"
#include "head-sensor/head-sensor.hpp"
#include "head-sensor/resources.hpp"
#include "sensors/ir-protocol-parser-MT2-ex.hpp"
#include "sensors/ir-physical-receiver-io-pin.hpp"
#include "output/rgb-vibro-io-pins.hpp"
#include "output/rgb-vibro-pwm.hpp"
#include "rcsp/stream.hpp"
#include "hal/system-controls.hpp"

#include <stdio.h>
#include <math.h>

HeadSensor::HeadSensor() :
	AnyRCSPClientDeviceBase(nullptr)
{
	deviceConfig.deviceType = DeviceTypes::headSensor;
	m_tasksPool.setStackSize(512);
	m_interrogator.setStackSize(512);
}

void HeadSensor::init(const Pinout &_pinout, bool isSdcardOk)
{
	if (!isSdcardOk)
	{
		error << "Fatal error: head sensor cannot operate without sdcard!";
	}
	//debug.enable();

	info << "Parsing config file";
	if (!m_aggregator.readIni("config.ini"))
	{
		error << "Cannot read config file, so setting default values";
		playerConfig.setDefault();
	}

	info << "Restoring last state and config";
	m_stateSaver.setFilename("state-save");
	// State restoring is always after config reading, so not stored data will be default
	if (m_stateSaver.tryRestore())
	{
		info << "  restored";
	} else {
		error << "  restoring failed, using default config";
		// setting player state to default
		playerState.reset();
		m_stateSaver.saveState();
	}

	info << "Network initialization";
	static_cast<OrdinaryNetworkClient*>(m_networkClient)->registerMyBroadcast(broadcast.anyGameDevice);
	static_cast<OrdinaryNetworkClient*>(m_networkClient)->registerMyBroadcast(broadcast.headSensors);
	static_cast<OrdinaryNetworkClient*>(m_networkClient)->registerMyBroadcastTester(new TeamBroadcastTester(playerConfig.teamId));

	info << "Other initialization";
	m_tasksPool.add(
			[this] { m_taskPoolStager.stage("m_statsCounter.interrogate()"); m_statsCounter.interrogate(); },
			200000
	);

	m_tasksPool.add(
			[this] { m_taskPoolStager.stage("PowerMonitor::interrogate()"); m_powerMonitor.interrogate(); },
			100000
	);

	m_tasksPool.add(
			[this] { m_mfrcCard.interrogate(); },
			10000
	);

	m_interrogator.registerObject(&m_weaponsManager);

	info << "Discovering bluetooth module";
	// First, configuring HC-05 bluetooth module to have proper name, UART speed and password
	bool hasBtModule = HC05Configurator::quickTestBluetooth(IOPins->getIOPin(IIOPin::PORTA, 1), UARTs->get(IUARTSPool::UART2));
	if (hasBtModule)
	{
	    info << "Initializing built-in bluetooth bridge device";
	    BluetoothBridge *bb = new BluetoothBridge(m_networkLayer);
	    bb->assignExistingNetworkLayer(m_networkLayer);
	    bb->initAsSecondaryDevice(_pinout, isSdcardOk);
	} else {
	    info << "Bluetooth module not installed, running without it";
	}

	info << "Configuring sensors";
	m_irProtocolParser = new IRProtocolParserMilesTag2Ex(m_aggregator, m_illuminationSchemes);
	m_receiverMgr.setParser(m_irProtocolParser);

	m_sensorsInitializer.read("sensors.ini");

	m_smartSensorsManager.init(UARTs->get(IUARTSPool::UART3));

	m_interrogator.registerObject(&m_receiverMgr);
	m_interrogator.registerObject(&m_ledVibroMgr);

	info << "Stats restoring";
	m_statsCounter.restoreFromFile();

	m_stateSaver.registerStateSaver(&m_statsCounter);

	m_tasksPool.run();
	m_stateSaver.runSaver(8000);

	m_interrogator.run();
	info << "Head sensor ready to use";


	m_mfrcCard.init();
	setFRIDToWriteAddr();

	// Statistics dubug
	m_statsCounter.clear();
	m_statsCounter.registerHit(25);
	m_statsCounter.registerHit(26);
	m_statsCounter.registerHit(27);
	m_statsCounter.registerDamage(25, 8);
	m_statsCounter.registerDamage(26, 9);
	m_statsCounter.registerDamage(27, 10);
	m_statsCounter.registerKill(25);
	m_statsCounter.registerKill(27);

	m_smartSensorsManager.run(
			[this](){ m_ledVibroMgr.applyIlluminationSchemeAllPoints(&(m_illuminationSchemes.init())); }
	);
}

void HeadSensor::initSmartZones(const Pinout &pinout)
{
    m_smartSensorsManager.init(UARTs->get(IUARTSPool::UART3));
}

void HeadSensor::resetToDefaults()
{
    taskENTER_CRITICAL();
    m_stateSaver.resetSaves();
    taskEXIT_CRITICAL();
    systemControls->rebootMCU();
    /*
    // Important!! Code below makes hard fault usually. And I dont know why.

	m_callbackStager.stage("reset");
	m_leds.blink(blinkPatterns.anyCommand);
	if (!m_aggregator->readIni("config.ini"))
	{
		error << "Cannot read config file, so setting default values";
		playerConfig.setDefault();
	}

	playerState.reset();
	m_stateSaver.resetSaves();
	m_stateSaver.saveState();

	// Hard fault-making code end
	 */
}

void HeadSensor::rifleToHeadSensorHeartbeat()
{
	if (!m_networkPackagesListener.hasSender())
		return;

	m_weaponsManager.updateWeapon(m_networkPackagesListener.sender());
	sendHeartbeat(m_networkPackagesListener.sender());
}
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

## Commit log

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2014-10-19 nrf register r/w works; testsd fails when audio buffer > appr. 100
    [main.cpp]
2014-10-29 Fact of transmission proved; flush does not work; adresses get/set impr; utils.hpp with systemTimer for delay
    [main.cpp]
2014-11-02 Radio works but strange error with low-power transmitter
2014-11-04 Small fix for payload size for radio; pipe 1 is enabled now. Fire led manager added
    [main.cpp]
2014-11-05 Miles tag shot impl; fire led broken
    [main.cpp]
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2014-12-06 MT2 receiver works; system clock jumps fix; jump detection test funcs moved to systemTimer;
    [main.cpp]
2014-12-06 MT2 transmitter-receiver pair works together (shots only now); bug in fire led fixed; debug receiver option added
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2014-12-17 Scheme improved, secial shematic elements for nfr24l01 and rfid-rc522 added
    [rifle.sch]
2014-12-18 Micro sd .lib; ready to tracing
    [rifle.kicad_pcb, rifle.sch]
2014-12-18 About a half of PCB
    [rifle.kicad_pcb, rifle.sch]
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2014-12-28 System clock (TIM4-TIM5) added, seems working but NOT heavy TESTED; MT2 transmitter implemented, NOT TESTED
    [resources mapping.ods]
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2015-01-09 Test shooting sound works
    [resources mapping.ods]
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2015-01-13 Head sensor schematic in process
    [head-sensor.sch, resources mapping.ods]
2015-01-14 Some connectors on scheme
    [head-sensor.sch]
2015-01-15 head sensor pcb beginned
    [head-sensor.kicad_pcb, head-sensor.sch]
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2015-01-16 head sensor pcb near no be done
    [head-sensor.kicad_pcb, head-sensor.sch]
2015-01-16 Head sensor pcb done
    [head-sensor.kicad_pcb]
2015-01-17 FW: SPI manager implemented, nrf24l01 device beginned, need input listener or some other object. HW: 3.5 terminals now used
    [head-sensor.kicad_pcb]
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2015-02-04 Wav player bug with strongly limited buffer size fixed, problem is in f_read. Work with slow cards fixed too
    [head-sensor.cpp, main.cpp]
2015-02-16 head sensor serial pcb beginned
    [head-sensor.kicad_pcb, head-sensor.sch]
2015-02-16 Head sensor routing done
    [head-sensor.kicad_pcb, head-sensor.sch]
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2015-02-17 head sensor v1.1 sended
    [head-sensor-B_Cu.gbl, head-sensor-B_Mask.gbs, head-sensor-Edge_Cuts.gbr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]
2015-02-19 Rifle rev.1.1 scheme seems done
    [rifle.kicad_pcb, rifle.sch]
2015-02-19 Rifle r1.1 pcb beginned
    [rifle.kicad_pcb, rifle.sch]
2015-02-19 WIP rifle 1.1 pcb
    [rifle.kicad_pcb, rifle.sch]
2015-02-20 Rifle pcb seems done
    [rifle.kicad_pcb, rifle.sch]
2015-02-20 Rifle design seems done
    [rifle.kicad_pcb]
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2015-02-23 Project for stm32f100 device created
    [resources - stm32f100cbt6b.ods, resources - stm32f103ret6.ods]
2015-02-23 simple IR RC schematic, pcb and some code
    [resources - stm32f100cbt6b.ods, resources - stm32f103ret6.ods, simple-ir-remote-control-rev1.kicad_pcb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]
2015-02-27 Large padded pin arrays of sizes 1..6 created, Rev 1.1 version of simple irrc created
    [simple-ir-remote-control-rev1.kicad_pcb, simple-ir-remote-control-rev1.sch]
2015-02-28 Simple irrc rev 1.1 done - better design for manual producing
    [$simple-ir-remote-control.sch, simple-ir-remote-control-rev1.kicad_pcb, simple-ir-remote-control.kicad_pcb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]
2015-02-28 Little fix
    [$simple-ir-remote-control.sch, simple-ir-remote-control.sch]
2015-03-01 MT2 -> RCSP connection beginned; Fix for regression of fire emitter for rifle
    [head-sensor.cpp]
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2015-03-08 Important fix for str parcer for complicated types. No player status synchronization works. Shooting damage is broken.
    [head-sensor.cpp]
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2015-03-10 Shooting enabled back. Bug with first shot - no header
    [head-sensor.cpp]
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2015-03-29 Sensor module for home mading created; Eclipse updated
    [cost-counting.ods, sensor-module.kicad_pcb, sensor-module.sch]
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2015-04-21 sensor module pcb fixed for vibroengine
    [sensor-module.kicad_pcb, sensor-module.sch]
2015-04-21 sensor module gerbers are done
    [sensor-module-B_Cu.gbl, sensor-module-B_Mask.gbs, sensor-module-B_SilkS.gbo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]
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2015-05-24 Some important fixes; bolt-only reloading works
    [config.ini]
2015-05-24 Auto reloading support added (not tested, but simple); death led pattern fixed
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2015-05-26 MCU module pcb created and close to be done
    [mcu-module.kicad_pcb, mcu-module.sch]
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2015-06-02 Head shield in process too
    [head-sensor-shield-v1-rev1.sch, rifle-shield-v1.sch]
2015-06-03 rifle shield done without indication
    [rifle-shield-v1.sch]
2015-06-04 rifle shield PCB beginned :/
    [rifle-shield-v1.kicad_pcb, rifle-shield-v1.sch]
2015-06-06 Rifle shield without display done
    [rifle-shield-v1.kicad_pcb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]
2015-06-07 Head sensor shield done
    [head-sensor-shield-v1-rev1.kicad_pcb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]
2015-06-12 It compiles. Link-time optimization is disabled! Otherwise FreeRTOS has linking error
    [bsp_driver_sd.c, bsp_driver_sd.h]
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2015-06-18 File access fixed: root cause if low stack size
    [bsp_driver_sd.c, main.cpp]
2015-06-19 Fix for rifle damage; task and mutex wrappers done
    [main.cpp]
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2015-07-26 Kill zones reenabled (not tested), shock delay head sensor side implemented (not tested). State saver fix - WIP
2015-07-31 vibroengines fixed, release configuration works. Head sensor seems working well
    [main.cpp]
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2015-08-26 Sound bug with sample cycling fixed
2015-08-28 Rifle support pinout from file now; all pins RESET at start added to prevent accidents with LEDS and other
    [io-pins.hpp]
2015-08-30 PCB: MCU2 connector orientation fixed; SOFT: Worker object added to os-wrappers, WavPlayer and IOPinsPool use it now
    [head-sensor-shield-v1-rev1.kicad_pcb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]
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2015-09-06 Bridge iron pcb created
    [bridge-iron-rev1.kicad_pcb, bridge-iron-rev1.sch]
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2015-10-09 Old rcsp removed, devices list fixed
2015-10-11 Values of PAM8403 resistors added
    [rifle-shield-v1.sch]
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2015-10-16 Revert button works, not equal sign not tested
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2015-10-25 Float variables support; fix for case when parameter iu element was not rendered till Apply pressed; other parameters added
2015-11-04 10x2 pin array centering fix
    [led power.ods]
2015-11-07 RTC and ADC support beginning. RTC wotks from external quartz
    [mcu-module.kicad_pcb]
2015-11-14 New head sensor board; some RTC and ADC code
    [head-sensor-shield-v2-rev1.kicad_pcb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]
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2015-11-16 MCU module rev2 done
    [head-sensor-shield-v2-rev1.kicad_pcb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]
2015-11-17 Pinout suports buttons inverting (not tested), RTC should determine if power VBAT losed
    [main.cpp, pinout.hpp]
2015-11-23 Fix for heartbeat; IDC sensor; rifle shield in process
    [rifle-shield-v1.kicad_pcb, rifle-shield-v1.sch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]
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2015-11-26 Logging through uart manager works, but some problems with async uart1
2015-12-04 Bug with sudden disabling of radio module fixed. Added workaround: probably some (?) modules have a bug: tx done flag and IRQ does not set sometimes
    [main.cpp]
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2015-12-08 Changing vector table works: no only fix in new CMSIS define needed; Standalone bootloader beginned
    [bsp_driver_sd.c, bsp_driver_sd.h, main.cpp]
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2016-01-20 new rifle pcb design
    [rifle-shield-v1.kicad_pcb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]
2016-01-22 Head and rifle boards done
    [head-sensor-shield.kicad_pcb, head-sensor-shield.sch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]
2016-01-24 Ferrite bead added to MCU module
    [mcu-module.kicad_pcb, mcu-module.sch]
2016-01-24 Prev. commit fix
    [mcu-module.sch]
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2016-03-26 Some job for registering unknown commads
    [head-sensor-shield.kicad_pcb, head-sensor-shield.sch]
2016-03-26 fix: Some untracked files added
    [bluetooth-bridge.kicad_pcb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]
2016-03-26 ADC fixed, Power monitor class added
    [config.ini, main.cpp]
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2016-03-31 SPI seems fixed for rifle when shooting
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2016-04-13 Some rifle pcb improvements: led is 1206, tants are type E, hw rf swith added
    [rifle-shield.kicad_pcb, rifle-shield.sch]
2016-04-15 New sensor module for LW round plastic sensor; leds are 1206, capacitors fixed
    [head-sensor-shield.kicad_pcb, mcu-module.kicad_pcb, mcu-module.sch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]
2016-04-22 Fix for lcd/rfid wires
2016-04-28 RFID now use RCSP. Change HS command added.
    [head-rifle-round-sensors.kicad_pcb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]
2016-05-26 Round sensor fix for TSOP orientation
    [head-rifle-round-sensors.kicad_pcb, sensor-module.kicad_pcb]
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2016-05-29 AndrStudio update; Fix for RFID
    [round_sensors_fixed_with_universal_board.kicad_pcb]
2016-06-30 damager notification fixed. Network timings changed. Timeouted packages removing improved
    [io-pins-hw.cpp]
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2016-07-05 Some old grouped boards with incorrect TSOP added
    [head-rifle-round-sensors-B_Cu.gbl, head-rifle-round-sensors-B_Mask.gbs, head-rifle-round-sensors-B_SilkS.gbo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]
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2016-09-04 [PCB] Fix for prev commit
    [ir-led-lw-compatible.kicad_pcb]
2016-09-04 [PCB] IR led module LW-compatible added
    [PCB] Fix for prev commit
    [ir-led-lw-compatible.kicad_pcb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]
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2016-09-20 [Android] Bluetooth connection interface improved. Autorun MainControlsActivity only once. Fixed disconnection when pressing back key on devices list activity.
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2016-09-25 [android] Bug fixes: text edit for parameters freeze; float input for integer; connecting when start screen orientation changed; useless checkbox on paired devices list
2016-09-26 [firmware] NRF24 communication via IRadioPhysical - radio module can be replaced now
    [bluetooth-bridge.cpp, head-sensor.cpp]
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2016-10-02 [PCB] Monolith head sensor board for fixed box beginned; [android] small IDE config change
    [hs-mono-g431.kicad_pcb, hs-mono-g431.sch]
2016-10-03 [PCB] monolith HS for G431 schematic fixed, NRF24L01 module added for 1100m variant
    [hs-mono-g431.sch]
2016-10-04 [PCB] Monolith HS beginned, initial jobs: board cuts, footprints added to list
    [hs-mono-g431.sch]
2016-10-09 [PCB] Monolith head sensor PCB first iteration done. Bluetooth added. Silk not ready
    [hs-mono-g431.kicad_pcb, hs-mono-g431.sch]
2016-10-09 Fix for prev commit
    [hs-mono-g431.sch]
2016-10-10 [PCB] Errors check in progress
    [hs-mono-g431.kicad_pcb, hs-mono-g431.sch]
2016-10-10 [PCB] Final silk fixes for mono hs
    [hs-mono-g431.kicad_pcb]
2016-10-11 [PCB] Plots for head sensor for G431 added
    [hs-mono-g431-panelized.kicad_pcb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]
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2016-10-16 [docs] Documents dirs structure fix
    [Universal connector pinout.ods, cost-counting.ods, led power.ods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]
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2016-11-03 [PCB] Monolith rifle board near pcb routing done, need silk fixes
    [rifle-mono-v1.kicad_pcb, rifle-mono-v1.sch]
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2016-11-06 [PCB] [firmware] Rifle monolith pcb final. Firmware build fix
    [rifle-mono-v1.kicad_pcb]
2016-11-06 [pcb] Rifle monolithic panelized done and send to factory
    [rifle-mono-v1-panelized.kicad_pcb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]
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2016-11-13 [firmware] Minor stability and grammar fixes
    [bluetooth-bridge.cpp, pinout.hpp]
2016-11-19 [firmware] Some refactoring, grammar fixes, added head sensor default pinout checking
    [bluetooth-bridge.cpp, hardware-initializer-hw.cpp, head-sensor.cpp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]
2016-11-27 [firmware] Fix for pinout checking function of head sensor; vibro engine enabled for any data signal to killzone
    [head-sensor.cpp, pinout.hpp, pinout.ini]
2016-11-27 [PCB] Head sensor fix: added UART/I2C pins to sensors connector
    [hs-mono-g431.kicad_pcb, hs-mono-g431.sch]
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2016-11-28 [PCB] Fix for tube sensor
    [_saved_sensor-tube.sch, sensor-tube.sch]
2016-11-29 [PCB] Boards group for latest HS and tube sensors. Python script for boards outline fixing
    [fixed-hs-g431-tube-sensors.kicad_pcb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]
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2016-12-09 [firmware] SDCard mutexes added, but head sensor unstable
    [bsp_driver_sd.c, utils_driver_sd.c]
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2016-12-12 [firmware] Fix for clock initialization, frequency is 72MHz again. SystemClock are now works correctly with prescaler = 72-1
    [new-universal-device.ioc]
2016-12-17 [firmware] Network client layer integration done. I cannot reproduce hard fault, may be IRQ priority=4 for SPI fixed. By the way fault handler improved
    [bluetooth-bridge.cpp, head-sensor.cpp]
2016-12-18 [firmware] All RCSPAggregator::instance() usages fixed. AnyDeviceBase class created. Design improved
    [bluetooth-bridge.cpp, head-sensor.cpp]
2016-12-20 [firmware] Broadcast for not-bluetooth-bridge added, corresponding fix for Android
    [head-sensor.cpp, new-universal-device.ioc]
2016-12-20 [firmware] Fixes for damager notification system: heartbeat always gives player id to rifle. Friend injuring sound added
    [head-sensor.cpp]
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2017-01-02 # WARNING: head commit changed in the meantime
    [firmware] Grammar fixes
    [head-sensor.cpp]
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2017-01-11 [android] Fixed settings back button bug and player list table separator bug
2017-01-12 [android] Increased client app stability through thread-safety workarounds
2017-01-12 [firmware, android] Fixed head sensor RGB LED pinout, added player position discovery in client Android app
    [head-sensor.cpp, pinout.ini]
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2017-01-13 [firmware] Hard fault handler improved. Minor bluetooth bridge fixes. Hard Faults do not take place if m_workerToBluetooth disabled
    [bluetooth-bridge.cpp]
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2017-01-14 [android] Fixed back button behavior in Settings
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2017-01-16 [firmware] Bluetooth bridge memory leak fixed
    [bluetooth-bridge.cpp, newlib.c]
2017-01-17 [firmware] Build fix for prev commit
    [bluetooth-bridge.cpp]
2017-01-26 [firmware] New IR subsystem works, vibration not reenabled yet
    [head-sensor.cpp]
2017-02-04 PWM support for internal illumination points added, ST copyrights updated
    [hs-mono-g431.sch]
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2017-02-11 Fixes for multiply receivers case
    [head-sensor.cpp]
2017-02-11 Fixes: RCSP aggregator ini reading major fix; head sensor reset to default hard fault fix; key sequences implemented but temporary disabled; lcd5110 support for card programming modes
    [head-sensor.cpp]
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2017-02-17 Bluetooth connection refactoring. Some fixes in RCSP and network
    [bluetooth-bridge.cpp]
2017-02-17 WIP, some improvements. Android app threading fixed
    [bluetooth-bridge.cpp]
2017-02-18 Some stability improvements: 1) printHex removed (had no mutex); 2) bluetooth timeout works correctly 3) Bluetooth package has checksum
    [bluetooth-bridge.cpp, bsp_driver_sd.c, hardware-initializer-hw.cpp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]
2017-02-19 Free heap and thread id output added to every debug message. System stability is at leat >14min if heap is enough.
    [bluetooth-bridge.cpp]
2017-02-26 Rifle mono board 1.1: capacitor near PAM; I2C pull-up; Laser TTL output
    [rifle-mono-v1.kicad_pcb, rifle-mono-v1.sch]
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2017-03-10 Grouped board with rifle and smart sensors fixed
    [rifle-and-sensors.kicad_pcb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]
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2017-04-08 Smart sensor animation reset support, ssp timings improved
2017-05-05 [firmware] Timeout fix, commands received by smart sensors are single now
2017-05-06 [firmware] Fix for heartbeat: died cannot shot. Initial sensors blink enabled for smart sensors. Little refactoring
    [head-sensor.cpp]
2017-06-01 [firmware] Only damaged sensors blinks when shot
    [head-sensor.cpp]
2017-06-21 [firmware] Audio interruptions fix; some other fixes
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2017-10-13 [firmware] Fix for double creation of NetworkLayer
    [head-sensor.cpp]
2017-10-24 [firmware] newlib.c now supports fatfs, so files should be accessed via fopen(...); RCSP push/pull/call renamed to this; Some code simplification for unit tests; unit tests (not working); Some forgot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
    [head-sensor.cpp, newlib.c]
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2017-11-14 [firmware] Some interface segregation, renaming and pinters to reference replacements
    [bluetooth-bridge.cpp, head-sensor.cpp]
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2017-12-26 [firmware] Important fix for splitBuffer [Android] settings editing in progress
    [bluetooth-bridge.cpp]
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2018-01-09 [Android] Statistics auto updating works, devices count update speed increased [firmware] reset player code fixed, some unused parameters removed
    [head-sensor.cpp]
2018-01-11 [firmware] Fix in network layer: the bug was that oly first local receiver gets a package. It appears when i.e. broadcast for all is sended by HS
    [bluetooth-bridge.cpp, head-sensor.cpp]
2018-01-12 [firmware] File writing fixed
    [newlib.c]
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

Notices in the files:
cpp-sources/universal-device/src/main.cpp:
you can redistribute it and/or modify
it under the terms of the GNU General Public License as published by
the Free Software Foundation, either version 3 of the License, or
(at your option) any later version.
